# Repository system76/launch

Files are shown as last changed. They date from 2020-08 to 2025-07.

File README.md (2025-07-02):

# System76 Launch Configurable Keyboard

The System76 Launch Configurable Keyboard is designed to provide the ultimate
user controlled keyboard experience, with open source mechanical and electrical
design, open source firmware and associated software, and a large number of
user configuration opportunities. It is registered open source hardware with
[OSHWA UID US001062](https://certification.oshwa.org/us001062.html).

- [Mechanical Design](#mechanical-design)
- [Electrical Design](#electrical-design)
- [Firmware and Software](#firmware-and-software)

## Mechanical Design

Chassis Image

### Open Source Chassis

The Launch chassis is licensed CC-BY-SA-4.0 and can be viewed in the
[chassis](./chassis/) folder using [FreeCAD](https://www.freecad.org).

### Milled Aluminum

The chassis is milled from two solid blocks of aluminum and powder coated to
provide excellent fit and finish. Each pocket, port, and hole is designed and
precisely machined so that swapping switches and plugging in cables is easy and
secure for the user.

### Detachable Lift Bar

The included lift bar can be magnetically secured to add 15 degrees of angle to
your keyboard for ergonomics.

### Innovative Layout

The layout is designed to provide a large number of remapping opportunities.
The default layout can be viewed
[here](http://www.keyboard-layout-editor.com/#/gists/8ec5e9026d616ebad6b2c7e9d943e7c0),
and the extra keys included can be viewed
[here](http://www.keyboard-layout-editor.com/#/gists/a3ad8710b27f78fd938077b2bf6d3ef5).

### Swappable Keycaps

The keycaps are PBT material with a dye sublimation legend and XDA profile to
provide excellent feel and lifespan. Extras are provided for common replacements
and color preference. An included keycap puller can be used to move and replace
the keycaps.

### Swappable Switches

The switches are mounted in sockets that support any RGB switch with an MX
compatible footprint. Examples are the Cherry MX RGB switches and the Kailh
BOX switches. Switches can be removed easily at any time with the included
switch puller.

## Electrical Design

PCB Image

### Open Source PCB

The Launch PCB is licensed GPLv3 and can be viewed in the
[pcb](./pcb/) folder using [KiCad](https://kicad.org/).

### Integrated Dock

Launch connects to a computer using the included USB-C to USB-C cable or USB-C
to USB-A cable. It supports USB 3.2 Gen 2 with speeds up to 10 Gbps with either
cable, provided the computer supports these speeds. It provides 2 USB-C and 2
USB-A connectors that also support USB 3.2 Gen 2, with the 10 Gbps bandwidth
shared between them on demand.

### Independent RGB Lighting

Each switch has an RGB LED that is independently controlled by firmware. This
allows for a number of RGB LED patterns to be selected.

### N-Key Rollover

The keyboard matrix uses diodes on all intersections, providing full independent
scanning of each key position.

## Firmware and Software

### Open Source Firmware

The Launch firmware is based on [QMK](https://github.com/system76/qmk_firmware),
licensed GPLv2, and the latest version is linked in the `firmware` submodule.

### Open Source Software

Projects that integrate with Launch are open source software, such as the
[System76 Keyboard Configurator](https://github.com/pop-os/keyboard-configurator),
licensed GPLv3, and [fwupd](https://github.com/fwupd/fwupd/), licensed LGPLv2.1.

### Easy Remapping

The keyboard can be remapped at runtime using the
[System76 Keyboard Configurator](https://github.com/pop-os/keyboard-configurator).
This utility runs on Linux, Mac OS, and Windows.

### Firmware Updates

Firmware updates are supported through the
[fwupd](https://github.com/fwupd/fwupd/) project, and are distributed using the
related Linux Vendor Firmware Service. Settings are stored on EEPROM and are
maintained through firmware updates.

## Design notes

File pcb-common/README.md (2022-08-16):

# Version Pins PB4-PB7

These are only present on boards with the AT90USB646 microcontroller
(Lite, Launch 2).

Pin PE1 will be grounded if a numeric keypad is present.

| Version | PB4  | PB5  | PB6  | PB7  |
|---|---|---|---|---|
| Lite 1.0 | open | open | open | open |
| Lite ISO 1.0 | open | open | open | open |
| Launch 2.0 | GND  | open | open | open |
| Launch ISO 2.0 | GND  | open | open | GND  |

# Part Substitutions

#### USB7xx6 USB hub

Can use USB7206 or USB7006 any PCB, USB7216 on any PCB >= Launch
1.1. Note that USB7006 is only Gen 1 USB.

 - USB7206: original, do not install R18, R28 if using, Gen 2 (10 Gb/s)
 - USB7216: alternate, install R18, R28, Gen 2 (10 Gb/s), has built Type-C support for 1 port which we are not using to retain ability to use USB7206.
 - USB7006: alternate, do not install R18, R28 if using, Gen 1 (5 Gb/s)

#### PTN5111 Type-C port controller

NXP introduced the PTN5110NHQZ and discontinued all others in the
PTN5110 line. It defaults to a toggling dual role port, will need to
be configured by software for the downstream facing ports. The
upstream facing port should select the correct mode. No hardware
changes are required.

 - PTN5110THQ: original for downstream ports (U12, U13), defaults to sourcing power
 - PTN5110DHQ: original for upstream port (U11), defaults to sinking power
 - PTN5110NHQZ: replacement, defaults to dual role port, same part used all 3 locations

#### Buck converters

Changes were all due to availability problems. Each part only works
with the listed PCB revisions.

 - TI TLV62585PDRL: Launch 1.0, 1.1
 - Diodes Inc. AP3441LSHE-7B: Launch 1.2, 1.4
 - Diodes Inc. AP61302: Launch 1.3
 - Aerosemi M3406-ADJ: Launch Lite 1.0 (includes ISO)
 - Aerosemi MT3410LB: Launch 2.0 (includes ISO)

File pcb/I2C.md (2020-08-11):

I2C addresses in this document include the R/W bit.

# USB Hub @ 0x5A

As I2C pullups are present on this board, the hub will wait for configuration before becoming active. The upstream superspeed mux should be set first.

# Type C Port Controllers (TCPC)
 - Register information is in PTN5110_AN2137.pdf rather than the data sheet.
 - The FRS pin is used as a GPIO to control the superspeed mux. See EXT_GPIO_CONFIG/CONTROL registers.
 - The interrupt pin is not wired due to lack of pins on the AVR. The TCPCs will need to be periodically polled. 
 - All support full USB PD communication, but this does not have to be used
 - Can source VCONN for active cables, electronic markers

## Upstream @ 0xA2
 - The CC_STATUS reigster can be read to determine connector orientation and available power.
 - A PD contract may allow more power than indicated in CC_STATUS, for example, a device that can source 2 A would report 1.5 A via CC_STATUS.
 - PTN5110DHQ which defaults to acting as a power sink.
 - Defaults should be OK except for GPIO setup on FRS.
## Downstream C Left @ 0xA4, Right @ 0xA0
 - PTN5110THQ which defaults to acting as a power source
 - The AVR will need to poll for cable connects and disconnects. tVbusOFF in the USB C spec is 650 ms which sets the maximum polling interval.
 - The SRC pin is used on the downstream ports to enable sourcing power. It may be required to switch the SRC pin to a GPIO so that sourcing power is only enabled after the superspeed mux is set properly.
 - It's probably best to only offer default power.

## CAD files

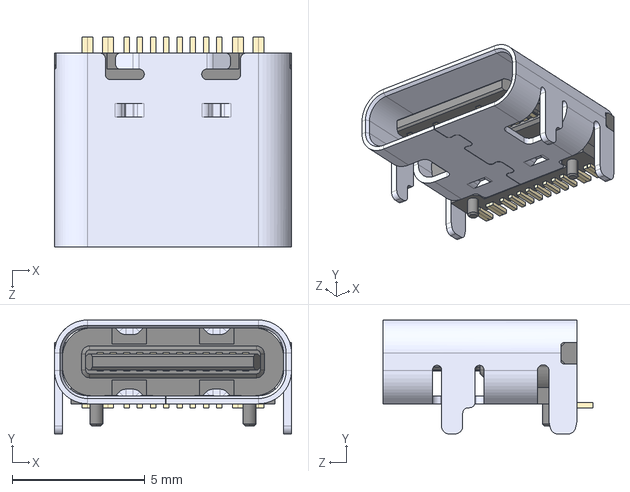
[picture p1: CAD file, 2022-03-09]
pcb/models/TYPE-C-31-M-12--3DModel-STEP-56544.STEP
8.94 x 4.30 x 7.90 mm

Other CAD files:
chassis/shared-components/CAD/AS_TEST_STABIL_ASM v2.step
chassis/launch-heavy/CAD/Key Caps.step
chassis/launch/CAD/KEYALU-002001.step
chassis/shared-components/CAD/PN-000173.step
packaging/Launch_Packaging_reference.step
pcb/models/GT-TC025D-H0065.step
chassis/launch-heavy/CAD/PN-000337 v19.step
chassis/launch-lite/CAD/PN-000166 v14.step
pcb/models/SOD128.step
chassis/launch-heavy/CAD/PN-000338 v10.step
chassis/launch-lite/CAD/PN-000164 v32.step
chassis/launch/CAD/Launch V1.step
pcb/models/AFC07-S20FCC-00.step
chassis/launch-heavy/CAD/PN-000336 v7.step
chassis/launch/CAD/KEYALU-001001.step
chassis/shared-components/CAD/PN-000163 v6.step
chassis/launch-heavy/CAD/Heavy Production V1.step
chassis/launch-heavy/CAD/PCB V1 - Physical Place Holder.step
chassis/launch-heavy/CAD/PN-000336 v7.f3d
chassis/launch-heavy/CAD/PN-000337 v19.f3d
chassis/launch-heavy/CAD/PN-000338 v10.f3d
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

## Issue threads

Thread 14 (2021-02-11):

North-facing switch socket interference

powwu, 2021-02-11:
Hello there!

This is just to let you know that, whether intentional or not, your board uses north facing switch sockets. This is not an issue with the included XDA profile caps, but when you switch in aftermarket caps, such as Cherry profile keycaps, [interference is possible](https://youtu.be/pFySgr0xmPw). This causes muffled sound and a bottom-out that feels mushy and uneven. Usually, north facing switch sockets are there to provide better RGB lighting when a key is "backlit" (transparent legending), but this is not the case here. This is a decently significant issue, because Cherry profile keycaps are the most popular among aftermarket keycaps. If you do a revision in the future, I recommend making your switch sockets south-facing.

jackpot51, 2021-02-11:
We have not seen (heard?) any such issue, and have used other keycaps in testing. I think the way the switch is plate mounted is pretty important

lennihein, 2021-02-12:
The issue exists, and is widely known by people that ever had any interest in keyboards. A design choice that doesn't make me very confident in the overall process of designing this board.

VinnyCordeiro, 2021-02-12:
> A design choice that doesn't make me very confident in the overall process of designing this board.

Agreed. I was excited about a new player on the market, specially one that promotes open source solutions like System76, but after taking a look at the design, being a keyboard PCB designer myself, the excitement cooled down significantly. That's unfortunate.

leviport, 2021-02-12:
To clarify: this is _only_ an issue with Cherry profile's row 4 keycaps. Pretty much all of the other keycap profiles out there (including the XDA caps this board was designed with and will ship with) do not interfere with north-facing switches.

> but after taking a look at the design, being a keyboard PCB designer myself, the excitement cooled down significantly. That's unfortunate.

Thanks for the feedback, but it's not very constructive. Is anything other than the switch orientation a big issue? We can only improve if we know where we went wrong.

WatchMkr, 2021-02-12:
Thank you for your input. It's appreciated. I am not experiencing interferences issue with cherry profiles. We tested DSA, XDA, Cherry, and VSA.

https://user-images.githubusercontent.com/3430283/107816382-e8b60480-6d31-11eb-93a3-b1d715d7a25a.MOV

lennihein, 2021-02-12:
I am quite fond of System76 overall, so I really want this to succeed. Heavily recommend to get a lot of input from both the Linux (user) and Keyboard Enthusiast (experts) communities to create a product that meets the bar.

WatchMkr, 2021-02-12:
Thanks again. The orientation is intentional. We did not want LEDs shining out from below the lower portion of the keycap.

Closed 2021-02-12.

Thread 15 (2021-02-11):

Where's the link to buy this one ?

alexserver, 2021-02-11:
In the readme there's no link to a store or form to buy this one.
Also, it doesn't say whether this keyboard is just in the design phase, or already in production.
Can you put the enough information in your readme to clarify this questions ?
- is it on sale already ?
- is this only a design ?
- where are the schemas to build one ?
- do I have to build the PCB using PCB printing services ?
- do you have plans to sell this one ?

leviport, 2021-02-11:
The readme is not a blog post or official announcement, so that information wouldn't be relevant here. This is just where all the source code lives. They are not ready for sale quite yet, but we will make announcements in all of the usual places when they are selling. All of the design files are in this repo, so you can try making one yourself if you want to.

Closed 2021-02-11.

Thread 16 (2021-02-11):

Cannot Open step Files in FreeCAD

monty11ez, 2021-02-11:
I'm using the current version in the Arch repos 0.18.5 and I get an error trying to open the file.

bflanagin, 2021-02-11:
Hey @monty11ez what step file are you trying to open? I was able to open up Launch V1.step using FreeCAD 0.18.5. I'll try the others for good measure, but knowing which one you tried would make things faster.

jacobgkau, 2021-02-11:
Are you seeing this error?

```
Traceback (most recent call last):
  File "<string>", line 1, in <module>
<class 'OSError'>: cannot read STEP file
```

If so, please initialize Git LFS on your system: https://git-lfs.github.com/

Then re-clone the repository and try opening the file again. (Until Git LFS is initialized, you would only be getting pointer text files when clonning the repo.) I can confirm FreeCAD opens the STEP files:

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

jackpot51, 2021-02-11:
I think we need to add instructions to the README, since many files are stored using GIT LFS and also we use submodules.

This is the correct way to clone the project:
```
git lfs install
git clone --recursive https://github.com/system76/launch.git
```

ultrasiq, 2021-02-13:
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

I did this and still can't open the .step files.

frankk74, 2021-02-22:
Step files are not fcstd files. They are an output file of CAD systems that cannot be used to edit (or very slightly). You can "import" step/stp or stl files and look at the design but it is not the full editable design. If possible can you post the fcstd files? I just wanted to look at the design elements. However, not choosing to post them to stop some other company from cloning your design is completely understandable. Thank you for posting the info that you have. Mind I couldn't find the info about the price/availability.

jackpot51, 2021-02-22:
@frankk74 the design is made in AutoCAD 360. There are STEP files of the assembly in various states. Individual parts as well as the full assembly. This is enough to import into other software like FreeCAD for editing.

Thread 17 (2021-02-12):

Remove reset to firmware command

jackpot51, 2021-02-12:
This was implemented in https://github.com/system76/qmk_firmware/commit/a1ab70c3a28a773aa116d2e37c3e597ca4c53c5b to make the flashing process easier.

However, this increases the risk that malicious keyboard firmware is installed without the user's consent. Therefore, remove the reset command and require the reset keycode (Fn+Esc) to be pressed, or the boot magic code (Esc while plugging in the keyboard) to reboot to the bootloader.

The risk is even higher when using an OS that does not require administrator privileges to access USB devices, such as Windows. And since we, by design so the user can customize things, do not have signed firmware - this means any application could potentially reflash the keyboard firmware.

By requiring a physical keypress to reboot the bootloader, at least the user will have to intentionally set the keyboard into this mode before firmware can be written.

jackpot51, 2021-02-25:
The firmware has been adjusted to require a manual unlock before it can be reset to bootloader and flashed.

Closed 2021-02-25.

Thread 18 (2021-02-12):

Feature request:  bluetooth version

ByteEnable, 2021-02-12:
Feature request:  bluetooth version.

leviport, 2021-02-12:
This request lacks information. If you can elaborate, I can reopen this issue.

ByteEnable, 2021-02-12:
The addition of a Bluetooth controller to the PCB for wireless keyboarding.

leviport, 2021-02-12:
Ah, a bluetooth version of the keyboard. Sorry, I'm not sure why I had trouble figuring out what you meant.

Thanks for the suggestion. I don't think the dock functionality is going to work well over bluetooth, and we're past the point of being able to make such major PCB revisions anyway. Perhaps bluetooth can come in future iterations though.

ruffsl, 2021-06-30:
> Perhaps bluetooth can come in future iterations though.

If one was to modify the current PCB design to include a bluetooth chipset for this functionality, would anyone have some recommendation on chipsets or radio ICs? A vendor with a friendly open source ecosystem for firmware and bluetooth profiles?

Closed 2021-02-12.

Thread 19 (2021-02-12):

Feature/Design request: Possibility to convert from ANSI to ISO standard

avila, 2021-02-12:
### Description:

It is great to hear you at system76 are producing a keyboard!  From the pictures I've seem so far it looks like the keyboard will follow the ANSI (American National Standards Institute) standard. It would be great if it would be possible to "switch" to the ISO standard. It mostly affects the `Enter` and `Shift` keys. See images below.

If this is physically impossible at this stage, please consider adding this feature in the next revisions.

### ISO keyboard standard:

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

### ANSI layout:

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

### System76 layout (looks like follows ANSI standard):

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

ogarcia, 2021-02-13:
And a full version with numpad

fuzebox1, 2021-03-29:
Id like to second this. I would really appreciate a ISO standards CAD and board layout file so i can print at home and have a board made locally! Although if you make one available for sale id definitely buy it when I finally buy a thelio :)

izzycampbell, 2021-03-29:
How much?

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

cooperspencer, 2025-07-12:
That would be great. I would immediately buy one

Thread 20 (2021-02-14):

Power (USB PD)

thibaultmol, 2021-02-14:
How many watts can the keyboard handle to charge a phone for example? Does it have USB PD?

jackpot51, 2021-02-15:
It does not have USB PD. The wattage delivered depends on the connection to the computer. If it is connected over USB-C, then a phone connected into a downstream USB-C port will be able to use around 15 watts

jackpot51, 2021-02-15:
A big reason it doesn't have USB-PD, is that computer motherboards do not support being a USB-PD source, and laptops are usually a sink but almost never a source. So it would require an additional AC adapter for full functionality

thibaultmol, 2021-02-15:
> A big reason it doesn't have USB-PD, is that computer motherboards do not support being a USB-PD source, and laptops are usually a sink but almost never a source. So it would require an additional AC adapter for full functionality

oh, interesting. Hadn't thought of that actually 👍

iMonZ, 2021-02-17:
> A big reason it doesn't have USB-PD, is that computer motherboards do not support being a USB-PD source, and laptops are usually a sink but almost never a source. So it would require an additional AC adapter for full functionality

Thats sad
but the idea of PD is still really great!

Closed 2021-02-15.

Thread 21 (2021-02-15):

TrackPoint (like Lenovo has) would be great.

guettli, 2021-02-15:
I am addicted to a TrackPoint, since it helps me to switch between typing and moving the mouse easily.

It would be great if you could provide something like this.

timvisee, 2021-02-15:
I agree! Though I'm afraid it won't fit between the mechanical switches without spacing the keys.

jackpot51, 2021-02-15:
We thought about it, but it was not easy to fit it into the reconfigurable design because it requires the GHB keycaps to have their corners clipped where the trackpoint would go. Additionally, finding trackpoint hardware is not easy

gzeronet, 2021-02-18:
Couldn't agree any more.
https://github.com/gzeronet/teensy-trackpoint-tmk-keyboard.git
https://github.com/gzeronet/tp60.git
It works for me, hope that can help. :)

Closed 2021-02-15.

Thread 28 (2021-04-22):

Add delay to escape key to avoid acidental reset

bflanagin, 2021-04-22:
When working on my computer yesterday my headphones tipped over and pressed the escape key on the launch right as I plugged in the device. This was a million in one shot, but it left my keyboard in a state that seemed broken until I reset the cable a second time.

To test:
Unplug the USB-C cable from the back of the keyboard. Just as you plug the cable back in slightly tap the escape key.

Solution:
If possible adding a small delay between power and checking for the escape key press might keep the device from being reset unintentionally.

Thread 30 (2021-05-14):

consider releasing the CAD source files

EllaBarker, 2021-05-14:
To keep the opensource/open hardware mindset I would appreciate it if the native CAD files get released beside the STEP ones.

jgrano, 2021-05-17:
Hi - The Step file is a much cleaner way to view the design/code if that's your thing. Our in house file format is F3D as we use Fusion 360 for design & manufacturing. Using Step is as close to universal as we can get so any can platform can import the design and you can modify as needed. We can easily import that changes as needed based on a Step file.

EllaBarker, 2021-05-17:
Releasing the STEP is the right decision as any program can import it but offering the native format, in addition, would be beneficial as modifying the native format is a better experience. That's in line with the recommendations from the OSHW: [https://www.oshwa.org/sharing-best-practices/](https://www.oshwa.org/sharing-best-practices/)
Just a simple, generic example: extend the case by 5 mm. With a native format, the only change would be updating the parameter. With step it is much more complicated and the easiest solution might be cut body, move, and inserting the new part in between.

There is software that claims they can convert a step, obj, igs, etc. back to native formats but in most cases, it fails miserably.

jgrano, 2021-06-25:
Haven't forgotten about this - I am unable to export the full assembly in a *.f3d format due to the distributed nature of the structure. A full step file export is the only option currently. I am pushing up the chassis designs in their native format.

Closed 2021-06-25.

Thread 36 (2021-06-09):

Feature request / bug report: Change USB-A type socket alignment

mvdkleijn, 2021-06-09:
## What?
From my perspective, the USB-A sockets are upside down.

## Reasoning
While I was unable to (quickly) find a relevant specification entry with regards to orientation, most reference images for the socket layout have the pin connectors located at the **top** of the socket. The same goes for the practical application on many, if not most or even all laptops. The pin connectors are at the top.

In the current keyboard design, the connector pins are at the bottom. This would force the user to turn around the USB-A type plug in order to insert it into the socket.

Though the orientation would in many cases probably not matter, there are important benefits to have the socket the right way up.

## Example
An important example is to allow for the insertion of a USB-A type security key such as promoted by the likes of Github and Google. Specifically the design of something like the Yubikey.

This would allow a user to insert the security key into the keyboard instead of the lap/desktop. This kind of key works fine on laptops because of the orientation of the USB-A type socket. However, the Launch keyboard's orientation would block a user from touching the confirmation button on the security key.

I hope you will be able to turn around the sockets... even better would be if a socket could be located on the right or left of the keyboard for easier access to the security key when you need to hit the confirmation button. 😄

jackpot51, 2021-06-17:
It has been impossible to find USB-A connectors that support 3.2 Gen 2 speeds that can be mounted on the same side but have the orientation reversed. To do this would mean pretty considerably increasing the size of the chassis

mvdkleijn, 2021-07-01:
> It has been impossible to find USB-A connectors that support 3.2 Gen 2 speeds that can be mounted on the same side but have the orientation reversed. To do this would mean pretty considerably increasing the size of the chassis

That's too bad... 😞 😢  Otherwise this would've been perfect. I guess I'll close this issue then.

Closed 2021-07-01.

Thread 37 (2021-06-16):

Shipping to China

eret9616, 2021-06-16:
I'm living in China mainland, In the Checkout process, there is no China , will there be adding this country

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

izzycampbell, 2021-06-16:
United States and what are you shipping anyways?

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

Closed 2021-06-17.

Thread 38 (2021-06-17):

Please see discussion on keebtalk

dkrikun, 2021-06-17:
Just have a look there, ok?

https://www.keebtalk.com/t/system76-open-source-hotswap-mechanical-keyboard/12946

mmstick, 2021-06-17:
Not worth wasting anyone's time.

jackpot51, 2021-06-17:
@dkrikun I really don't get how so many people can miss the fucking point so much

dkrikun, 2021-06-17:
Maybe you could elaborate?

jackpot51, 2021-06-17:
Sure, though I doubt it will matter. Most of the complaints I see center around the layout and the price.

**Layout**

The layout is specifically designed to minimize changes from the standard layout while introducing several impactful changes that show up on literally no other keyboards. Some mistake this for a lack of research when the exact opposite is true. We experimented heavily with common layouts, including ortholinear, split ortholinear, and staggered. We experimented with the "standard" key sizes, where the left side would line up perfectly, but would also use 1.25, 1.75, and 2.25 size keys. After a ton of prototypes, we arrived at this layout. Our first task was to reduce the number of key sizes, to maximize where keys could be swapped. This led to the left side and right side being uneven, but in a way I think looks good once you actually use the keyboard. We also split the spacebar, to allow both side to be mapped independently, and allow the caps to be swapped with anything else that has a 2U cap. We include tons of extras to ensure most keys can be put most anywhere. Keep in mind, that while enthusiasts don't care if caps are blank, most users do. This is a keyboard we want any of our customers to be able to use.

**Electrical Design**

Some absolute idiot suggested we have 5 USB ports as though it was a dumb idea. We do, but one is for connecting to the PC. So we have two USB-A and two USB-C ports on each side of that central connector to the PC, it is balanced and even and sensible. To have a 4-port 10Gbps USB hub inside a keyboard, certain things have to be done with the electrical layout. Trying to make it "pretty" is a mistake. Our layout is designed to maximize the USB lane integrity, critical for any high speed design. The switches themselves operate at extremely low frequency compared. We are talking 10 GHz compared to 1 KHz, several orders of magnitude lower. So, the switch and LED lines are moved around to make substantial room for ground planes and the important USB lines. It was not auto-routed AT ALL, this was done by hand with a careful consideration for high speed design requirements.

**Price**

Sure, you can have a 75% for less. With a metal chassis, good caps, and good switches you are approaching the Launch price. Throw in an integrated 4-port 10Gbps USB hub, and you won't find anything else available. Make it not integrated, and you still end up around the price we have for this keyboard. Our costs and profit margins are well researched and match those of other keyboards. If anything, we are in a position to outperform them on price in the future, as we have seen incredible demand for this product from our customers.

jackpot51, 2021-06-17:
Put that reply up on keebtalk because I'm so damn tired of the hate of this product building out of control:

https://www.keebtalk.com/t/system76-open-source-hotswap-mechanical-keyboard/12946/46?u=jackpot51

Closed 2021-06-17.

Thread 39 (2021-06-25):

request: rendered pdf schematic

hanetzer, 2021-06-25:
I'm running kicad nightly (I think the 6.0 release should come soon) and as such have to remap a fair
amount of symbols in the schematic. It would be very helpful to this endeavor if a rendered pdf of how
it 'should' look was included in the repository in case something is not clear from the old-style symbol
names.

leviport, 2021-06-25:
Are the PDFs in the `Drawings` directory what you had in mind? https://github.com/system76/launch/tree/master/chassis/Drawings

Sorry if I'm missing your meaning. I'm not very well-versed in CAD related matters :sweat_smile:

jackpot51, 2021-06-25:
This is schematics for electrical design. Currently we use KiCad 5.1.9. I can render them a bit later.

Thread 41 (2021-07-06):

Programming for Each OP for VF-5

CCooper20, 2021-07-06:

CCooper20, 2021-07-06:
Simulator for VF-5 with correct parameter
Program with 5 pallets for each:

- [ ] OP1-UH
- [ ] OP2-UH
- [ ] OP3-UH
- [ ] OP1-LH (vacuum system)
- [ ] OP2-LH (vacuum system)
- [ ] OP1-AB
- [ ] OP2-AB

- [ ] Sub program for chip fan

*pattern for programs / sub programs
*assigned G## for each pallet and color coordinated

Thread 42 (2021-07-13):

Work flow for Launch within Production

CCooper20, 2021-07-13:
Detailed document laying out each step for making LH, UH, AB and assembly.
Attached QC layout of checking imported parts.

CCooper20, 2021-07-13:
Work flow for each part, assembly and imported parts:

- [ ] LH
- [ ] UH
- [ ] AB

- [ ] Assembly

- [ ] Testing

- [ ] Imported parts

CCooper20, 2021-07-13:
Here is the current doc: [https://docs.google.com/presentation/d/1gIdjVxumpAt9Q0GdWsTyjt4Vi-lHfbOouB-Df1y45Go/edit?usp=sharing] (url)

CCooper20, 2021-08-02:
Where is the link again for this process and where are we at with documenting the assembly and also checking imported parts? @jgrano

jgrano, 2021-08-02:
@CCooper20 Import doc - https://docs.google.com/document/d/1v5RxfDeCSvyY8Mp5XGhm-rX4il3qUbCLlkyPOkBjI2c/edit?usp=sharing

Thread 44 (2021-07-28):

Implement OP1 / OP2 Vacuum process for LH

CCooper20, 2021-07-28:
New CNC programs / WI / QC checks

CCooper20, 2021-07-28:
- [ ] Design / Setup CNC toolpaths for vac pallets LH
- [ ] Setup Vacuum pallets for OP1 / OP2 LH
- [ ] Test

*made total of 5 complete pieces. Need to adjust T1 just for OP1-LH - 7/21/21

- [ ] Install vacuum pressure sensor on Haas
- [ ] WI for Vacuum pallets setup / main. and break down

- [ ] WI for OP1/OP2 LH
- [ ] Train Production to hand off - rev Work flow and CNC WI to match changes after we went through version 1 of LH pallets

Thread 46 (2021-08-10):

Update Drawings

jgrano, 2021-08-10:
Update Full Drawings based on new production methods

CCooper20, 2021-08-12:
Update Drawings for Launch:

Make sure all drawings are in one location and same template.

- [ ] KEYALU-003002 (last version of angle bar)
- [ ] KEYALU-003001 (obsolete drawing)
- [ ] KEYALU-001001
- [ ] KEYALU-002001
- [ ] Launch assembly drawing
- [ ] Launch steel plate / fix to steel disk

42Surtr, 2021-08-17:
Could any one can point out which of the file is the PCB file, which file can be checked and modified to build a pcb file?

leviport, 2021-08-17:
@42Surtr it's in the `pcb` directory: https://github.com/system76/launch/tree/master/pcb

42Surtr, 2021-08-19:
Thanks for your help.  There is anohter question for me is that is this PCB designed as a single layer PCB?  The PCB file is a little difficult to understand for me.

jackpot51, 2021-08-19:
@42Surtr it is a four layer PCB

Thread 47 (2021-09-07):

Failing to flash the Launch keyboard's firmware.

uncivilgentleman, 2021-09-07:
Following the documentation I'll link to on the bottom.  I modified the keymap.c file the way I wanted it.  The problem is the instructions to send the new .hex file to the keyboard aren't working.  It compiles just fine but I keep getting the ERROR: Bootloader not found. Trying again in 5s. even after unplugging the keyboard and plugging it back in while holding the ESC key.   The keyboard lights don't turn on but the error persists and nothing gets uploaded to the keyboard.

https://github.com/system76/qmk_firmware/blob/master/keyboards/system76/launch_1/README.md

_I realize this probably isn't the best place to post this problem but I can't find a better place.  All the official social platforms to engage with the company and its community seem to be proprietary social media platforms like Facebook, Twitter, and Telegram. I don't want to be a part of those places._

leviport, 2021-09-07:
Are you holding Esc while plugging in your Launch? It can be released a couple seconds after Launch is plugged in. Are you doing that while it's cycling that Bootloader not found message?

uncivilgentleman, 2021-09-07:
yes I'm holding ESC while plugging in the keyboard.  I've also tried different USB ports (Type A and C) on the computer.

leviport, 2021-09-07:
Hmm, what happens if you hold Fn+Esc instead? If that works, then I'll need to update those instructions.

uncivilgentleman, 2021-09-07:
That didn't work either.

uncivilgentleman, 2021-09-07:
I'm on Fedora 34 and not Pop-OS if that matters.   I don't know why it would but I figure I should mention it.

leviport, 2021-09-07:
QMK isn't at all specific to Pop, so that should still work. What version of `avrdude` do you have installed?

uncivilgentleman, 2021-09-07:
avrdude 6.3.  Specifically avrdude-6.3-20.fc34.src.rpm

leviport, 2021-09-07:
I'm also on 6.3. I'm wondering if a udev rule needs to be set or something. I'll spin up F34 on a lab machine and see if I can figure out how to QMK flash my Launch from it.

leviport, 2021-09-07:
Alright, I was able to get it dfu-programmer to recognize my Launch if I ran the make command with `sudo`. It also first asked me to run `util/qmk_install.sh` again, so I also ran that with `sudo`. Can you give that a try?

uncivilgentleman, 2021-09-07:
Yup that works!  I thought about doing that several times, should have.

leviport, 2021-09-07:
Glad to hear it! Not sure why Fedora requires `sudo` for that when Pop doesn't, but I can probably make a note of that in the instructions.

Oh and to address your note about social media platforms, there's also the Pop!\_OS chat where we even have a Launch Keyboard channel. It's a Mattermost instance that we host ourselves, so you can chat with us there without making accounts on social media platforms. You can find it at https://chat.pop-os.org if you're interested.

uncivilgentleman, 2021-09-07:
Awesome!  Thank you for the help :)

Closed 2021-09-07.

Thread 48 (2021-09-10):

Layer LEDs stay on after pressing Fn key

gondolyr, 2021-09-10:
**Software**: System76 Keyboard Configurator 1.0.0
**Operating System**: Windows 10 (10.0.19041 Build 19041)
**Firmware Version**: Launch 1.3?

My configuration is set up to turn on the LEDs for the bound keys on layers 2+. Every 13-20 presses (on average) of using the Fn key to Play/Pause the current media file, the LEDs stay on after I have let go of the Fn key. If I press the Fn key again, the LEDs turn off.

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

My current configuration is below:
```json
{
  "model": "system76/launch_1",
  "version": 1,
  "map": {
    "K04": [
      "F4",
      "ROLL_OVER",
      "ROLL_OVER",
      "ROLL_OVER"
    ],
    "K4C": [
      "UP",
      "PGUP",
      "ROLL_OVER",
      "ROLL_OVER"
    ],
    "K42": [
      "X",
      "ROLL_OVER",
      "ROLL_OVER",
      "ROLL_OVER"
    ],
    "K44": [
      "V",
      "ROLL_OVER",
      "ROLL_OVER",
      "ROLL_OVER"
    ],
    "K0C": [
      "F12",
      "ROLL_OVER",
      "ROLL_OVER",
      "ROLL_OVER"
    ],
    "K27": [
      "U",
      "PGDN",
      "ROLL_OVER",
      "ROLL_OVER"
    ],
    "K03": [
      "F3",
      "ROLL_OVER",
      "ROLL_OVER",
      "ROLL_OVER"
    ],
    "K50": [
      "LEFT_CTRL",
      "ROLL_OVER",
      "ROLL_OVER",
      "ROLL_OVER"
    ],
    "K5A": [
      "DOWN",
      "PGDN",
      "ROLL_OVER",
      "ROLL_OVER"
    ],
    "K14": [
      "4",
      "ROLL_OVER",
      "ROLL_OVER",
      "ROLL_OVER"
    ],
    "K57": [
      "RIGHT_ALT",
      "ROLL_OVER",
      "ROLL_OVER",
      "ROLL_OVER"
    ],
    "K37": [
      "J",
      "DOWN",
      "ROLL_OVER",
      "ROLL_OVER"
    ],
    "K46": [
      "N",
      "ROLL_OVER",
      "ROLL_OVER",
      "ROLL_OVER"
    ],
    "K3B": [
      "QUOTE",
      "ROLL_OVER",
      "ROLL_OVER",
      "ROLL_OVER"
    ],
    "K06": [
      "F6",
      "ROLL_OVER",
      "ROLL_OVER",
      "ROLL_OVER"
    ],
    "K41": [
      "Z",
      "ROLL_OVER",
      "ROLL_OVER",
      "ROLL_OVER"
    ],
    "K21": [
      "Q",
      "ROLL_OVER",
      "ROLL_OVER",
      "ROLL_OVER"
    ],
    "K0A": [
      "F10",
      "ROLL_OVER",
      "ROLL_OVER",
      "ROLL_OVER"
    ],
    "K26": [
      "Y",
      "HOME",
      "ROLL_OVER",
      "ROLL_OVER"
    ],
    "K40": [
      "LEFT_SHIFT",
      "ROLL_OVER",
      "ROLL_OVER",
      "ROLL_OVER"
    ],
    "K52": [
      "FN",
      "ROLL_OVER",
      "ROLL_OVER",
      "ROLL_OVER"
    ],
    "K1D": [
      "BKSP",
      "ROLL_OVER",
      "ROLL_OVER",
      "ROLL_OVER"
    ],
    "K31": [
      "A",
      "ROLL_OVER",
      "ROLL_OVER",
      "ROLL_OVER"
    ],
    "K0B": [
      "F11",
      "ROLL_OVER",
      "ROLL_OVER",
      "ROLL_OVER"
    ],
    "K36": [
      "H",
      "LEFT",
      "ROLL_OVER",
      "ROLL_OVER"
    ],
    "K33": [
      "D",
      "ROLL_OVER",
      "ROLL_OVER",
      "ROLL_OVER"
    ],
    "K43": [
      "C",
      "ROLL_OVER",
      "ROLL_OVER",
      "ROLL_OVER"
    ],
    "K07": [
      "F7",
      "ROLL_OVER",
      "ROLL_OVER",
      "ROLL_OVER"
    ],
    "K2A": [
      "P",
      "ROLL_OVER",
      "ROLL_OVER",
      "ROLL_OVER"
    ],
    "K4B": [
      "RIGHT_SHIFT",
      "ROLL_OVER",
      "ROLL_OVER",
      "ROLL_OVER"
    ],
    "K54": [
      "SPACE",
      "ROLL_OVER",
      "ROLL_OVER",
      "ROLL_OVER"
    ],
    "K5B": [
      "RIGHT",
      "END",
      "ROLL_OVER",
      "ROLL_OVER"
    ],
    "K00": [
      "ESC",
      "RESET",
      "ROLL_OVER",
      "ROLL_OVER"
    ],
    "K0E": [
      "HOME",
      "PLAY_PAUSE",
      "ROLL_OVER",
      "ROLL_OVER"
    ],
    "K11": [
      "1",
      "ROLL_OVER",
      "ROLL_OVER",
      "ROLL_OVER"
    ],
    "K18": [
      "8",
      "ROLL_OVER",
      "ROLL_OVER",
      "ROLL_OVER"
    ],
    "K2C": [
      "BRACE_CLOSE",
      "ROLL_OVER",
      "ROLL_OVER",
      "ROLL_OVER"
    ],
    "K1B": [
      "MINUS",
      "KBD_DOWN",
      "ROLL_OVER",
      "ROLL_OVER"
    ],
    "K1C": [
      "EQUALS",
      "KBD_UP",
      "ROLL_OVER",
      "ROLL_OVER"
    ],
    "K55": [
      "SPACE",
      "ROLL_OVER",
      "ROLL_OVER",
      "ROLL_OVER"
    ],
    "K2E": [
      "PGDN",
      "VOLUME_DOWN",
      "ROLL_OVER",
      "ROLL_OVER"
    ],
    "K29": [
      "O",
      "END",
      "ROLL_OVER",
      "ROLL_OVER"
    ],
    "K39": [
      "L",
      "RIGHT",
      "ROLL_OVER",
      "ROLL_OVER"
    ],
    "K4A": [
      "SLASH",
      "ROLL_OVER",
      "ROLL_OVER",
      "ROLL_OVER"
    ],
    "K53": [
      "LEFT_SUPER",
      "ROLL_OVER",
      "ROLL_OVER",
      "ROLL_OVER"
    ],
    "K16": [
      "6",
      "ROLL_OVER",
      "ROLL_OVER",
      "ROLL_OVER"
    ],
    "K19": [
      "9",
      "ROLL_OVER",
      "ROLL_OVER",
      "ROLL_OVER"
    ],
    "K10": [
      "TICK",
      "ROLL_OVER",
      "ROLL_OVER",
      "ROLL_OVER"
    ],
    "K28": [
      "I",
      "PGUP",
      "ROLL_OVER",
      "ROLL_OVER"
    ],
    "K56": [
      "RIGHT_CTRL",
      "ROLL_OVER",
      "ROLL_OVER",
      "ROLL_OVER"
    ],
    "K34": [
      "F",
      "ROLL_OVER",
      "ROLL_OVER",
      "ROLL_OVER"
    ],
    "K35": [
      "G",
      "ROLL_OVER",
      "ROLL_OVER",
      "ROLL_OVER"
    ],
    "K15": [
      "5",
      "ROLL_OVER",
      "ROLL_OVER",
      "ROLL_OVER"
    ],
    "K32": [
      "S",
      "ROLL_OVER",
      "ROLL_OVER",
      "ROLL_OVER"
    ],
    "K1A": [
      "0",
      "KBD_TOGGLE",
      "ROLL_OVER",
      "ROLL_OVER"
    ],
    "K51": [
      "LEFT_ALT",
      "ROLL_OVER",
      "ROLL_OVER",
      "ROLL_OVER"
    ],
    "K2D": [
      "BACKSLASH",
      "ROLL_OVER",
      "ROLL_OVER",
      "ROLL_OVER"
    ],
    "K48": [
      "COMMA",
      "MEDIA_PREV",
      "ROLL_OVER",
      "ROLL_OVER"
    ],
    "K45": [
      "B",
      "ROLL_OVER",
      "ROLL_OVER",
      "ROLL_OVER"
    ],
    "K08": [
      "F8",
      "ROLL_OVER",
      "ROLL_OVER",
      "ROLL_OVER"
    ],
    "K0D": [
      "DEL",
      "ROLL_OVER",
      "ROLL_OVER",
      "ROLL_OVER"
    ],
    "K12": [
      "2",
      "ROLL_OVER",
      "ROLL_OVER",
      "ROLL_OVER"
    ],
    "K05": [
      "F5",
      "ROLL_OVER",
      "ROLL_OVER",
      "ROLL_OVER"
    ],
    "K02": [
      "F2",
      "ROLL_OVER",
      "ROLL_OVER",
      "ROLL_OVER"
    ],
    "K17": [
      "7",
      "ROLL_OVER",
      "ROLL_OVER",
      "ROLL_OVER"
    ],
    "K23": [
      "E",
      "ROLL_OVER",
      "ROLL_OVER",
      "ROLL_OVER"
    ],
    "K58": [
      "FN",
      "ROLL_OVER",
      "ROLL_OVER",
      "ROLL_OVER"
    ],
    "K59": [
      "LEFT",
      "HOME",
      "ROLL_OVER",
      "ROLL_OVER"
    ],
    "K38": [
      "K",
      "UP",
      "ROLL_OVER",
      "ROLL_OVER"
    ],
    "K13": [
      "3",
      "ROLL_OVER",
      "ROLL_OVER",
      "ROLL_OVER"
    ],
    "K30": [
      "CAPS",
      "ROLL_OVER",
      "ROLL_OVER",
      "ROLL_OVER"
    ],
    "K1E": [
      "PGUP",
      "VOLUME_UP",
      "ROLL_OVER",
      "ROLL_OVER"
    ],
    "K2B": [
      "BRACE_OPEN",
      "ROLL_OVER",
      "ROLL_OVER",
      "ROLL_OVER"
    ],
    "K3C": [
      "ENTER",
      "ROLL_OVER",
      "ROLL_OVER",
      "ROLL_OVER"
    ],
    "K49": [
      "PERIOD",
      "MEDIA_NEXT",
      "ROLL_OVER",
      "ROLL_OVER"
    ],
    "K01": [
      "F1",
      "ROLL_OVER",
      "ROLL_OVER",
      "ROLL_OVER"
    ],
    "K47": [
      "M",
      "ROLL_OVER",
      "ROLL_OVER",
      "ROLL_OVER"
    ],
    "K3A": [
      "SEMICOLON",
      "ROLL_OVER",
      "ROLL_OVER",
      "ROLL_OVER"
    ],
    "K20": [
      "TAB",
      "PRINT_SCREEN",
      "ROLL_OVER",
      "ROLL_OVER"
    ],
    "K3D": [
      "END",
      "MUTE",
      "ROLL_OVER",
      "ROLL_OVER"
    ],
    "K24": [
      "R",
      "ROLL_OVER",
      "ROLL_OVER",
      "ROLL_OVER"
    ],
    "K25": [
      "T",
      "ROLL_OVER",
      "ROLL_OVER",
      "ROLL_OVER"
    ],
    "K22": [
      "W",
      "ROLL_OVER",
      "ROLL_OVER",
      "ROLL_OVER"
    ],
    "K09": [
      "F9",
      "ROLL_OVER",
      "ROLL_OVER",
      "ROLL_OVER"
    ]
  },
  "key_leds": {
    "K19": null,
    "K3A": null,
    "K56": null,
    "K48": null,
    "K53": null,
    "K10": null,
    "K16": null,
    "K24": null,
    "K28": null,
    "K1B": null,
    "K1D": null,
    "K5A": null,
    "K25": null,
    "K45": null,
    "K04": null,
    "K51": null,
    "K23": null,
    "K3B": null,
    "K06": null,
    "K26": null,
    "K1A": null,
    "K0A": null,
    "K34": null,
    "K52": null,
    "K36": null,
    "K2E": null,
    "K35": null,
    "K2A": null,
    "K18": null,
    "K11": null,
    "K44": null,
    "K01": null,
    "K05": null,
    "K40": null,
    "K42": null,
    "K32": null,
    "K4B": null,
    "K57": null,
    "K00": null,
    "K1E": null,
    "K17": null,
    "K2C": null,
    "K3C": null,
    "K33": null,
    "K37": null,
    "K08": null,
    "K59": null,
    "K03": null,
    "K1C": null,
    "K14": null,
    "K58": null,
    "K2B": null,
    "K39": null,
    "K47": null,
    "K20": null,
    "K09": null,
    "K30": null,
    "K0E": null,
    "K07": null,
    "K13": null,
    "K54": null,
    "K50": null,
    "K29": null,
    "K4C": null,
    "K2D": null,
    "K46": null,
    "K49": null,
    "K3D": null,
    "K43": null,
    "K15": null,
    "K0B": null,
    "K4A": null,
    "K38": null,
    "K21": null,
    "K41": null,
    "K12": null,
    "K02": null,
    "K31": null,
    "K55": null,
    "K22": null,
    "K5B": null,
    "K0C": null,
    "K27": null,
    "K0D": null
  },
  "layers": [
    {
      "mode": [
        14,
        127
      ],
      "brightness": 176,
      "color": [
        142,
        255
      ]
    },
    {
      "mode": [
        13,
        127
      ],
      "brightness": 176,
      "color": [
        142,
        255
      ]
    },
    {
      "mode": [
        13,
        127
      ],
      "brightness": 176,
      "color": [
        142,
        255
      ]
    },
    {
      "mode": [
        13,
        127
      ],
      "brightness": 176,
      "color": [
        142,
        255
      ]
    }
  ]
}
```

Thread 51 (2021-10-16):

Can the diameter of the through hole be adjusted from 0.40mm to 0.45mm?

zhangguanzhang, 2021-10-16:
Under the technology of most countries, the two sizes of 0.40mm and 0.45mm are manufactured by factory pcb at two different prices.
Can the diameter of the through hole be adjusted from 0.40mm to 0.45mm?
@jackpot51 @dlharmon 😘

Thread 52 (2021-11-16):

Add caps lock led indicator

HEX0101, 2021-11-16:
Considering that keyboard has bunch of LEDs, it would be useful it keyboard changed color when caps lock is on.

hiruko-san, 2022-03-05:
I would add to this and suggest something like turn the LED into a different colour when Caps Lock is On.
eg. Layer 1 LED is White, when Caps Lock is On, the LED on the Caps Lock key would turn Green.
Or when Layer1 LED is Disabled, the LED would light up in Green when Caps Lock is On.

billpayne4x4, 2022-08-14:
It would be nice if there was a Caps Lock modifier to all the LED layers so you could set a different layer patter/color when the Caps Lock was down.

leviport, 2023-02-03:
>But I suppose this keyboard cannot get new features. I'm guessing it's a board with hardware features, where software can just fill up some registers to map keys. I don't think a feature like this can be added now. Maybe in V2, which I'll never buy since this keyboard was already expensive enough.

The firmware controls everything, not just keymapping. This is probably something that could be implemented in firmware, it's just super tricky to do, since you somehow have to account for whatever color the LED was previously, and whether or not it is changing because of an animation.

The firmware is here, if anyone wants to give it a try: https://github.com/system76/qmk_firmware/

Just be careful not to brick it with a firmware flash while you tinker.

taivlam, 2023-03-12:
Now that the Launch Heavy version has been out for a bit, I'd also like to
suggest adding an LED indicator for the <kbd>Num Lock</kbd> key - since in the
meantime I've been using the [Lock Keys](https://extensions.gnome.org/extension/36/lock-keys/)
extension for GNOME to make sure I don't have the <kbd>Caps Lock</kbd> on by
accident or have the <kbd>Num Lock</kbd> key off by accident.

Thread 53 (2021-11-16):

Selma test program

CaryHertert, 2021-11-16:
Launch's Selma test program removes keymap if the operator does not press the stop button after initiating the switch test.  Can we change this to a set duration that doesnt require input from the operator?  The physical  test takes 2 minutes.

leviport, 2022-11-02:
I believe this has been addressed

Closed 2022-11-02.

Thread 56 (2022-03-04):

Layer 2 get's locked on when using Access Layer 2 key

ahoneybun, 2022-03-04:
Issue:

When using the attached layout and tapping the Access Layer 2 key multiple times in a row the lights can get stuck like in this video:

https://user-images.githubusercontent.com/4884946/156797924-43564511-e847-4ce7-86a0-428e8ad6f548.mp4

[launch_layout_1.zip](https://github.com/system76/launch/files/8187169/launch_layout_1.zip)

hiruko-san, 2022-03-10:
the issue usually happens when I'm adjusting my volume, so it's just one single key press on the "access layer 2" / "Fn" key, or to be precise, a single press & hold, while I adjust the volume with "+" or "-" or mute. It's random and purely based on chance when it happens.

I've also noticed this only happens if I don't have any lights on the first layer, (i.e. Layer 1 LED is completely disabled). For example, if I set Layer 1 LED to all white, Layer 2 to Blue for "bound keys only", I could not recreate this issue, it will always return to white LED.

gondolyr, 2022-03-21:
I'm glad I'm not the only one experiencing this issue.

I didn't get any responses in my previous filing here: https://github.com/system76/launch/issues/48

leviport, 2023-03-06:
This _might_ be fixed by https://github.com/system76/qmk_firmware/pull/34

andy0130tw, 2023-03-18:
@leviport I tried the provided PR, but it was not fixed.

zerobearing2, 2023-05-25:
having same issue

andy0130tw, 2025-04-19:
After years of usage, I have convinced myself that this lighting issue comes from some synchronization issue that may not be solvable.

Referring to the schematic diagram of this board, the LEDs are connected like a long strip. If you observe more lighting glitches, you will notice that the top row is more frequently glitched than others, and they are at the farther end of the LED strip. My theory is that the time duration pressing/releasing a key in succession is often too brief for the entire set of LEDs to react to the signal, and some signal are lost afterwards.

I am not a hardcore keyboard guy (even not a hardware guy), so if someone can help elaborate on this, I will greatly appreciate.

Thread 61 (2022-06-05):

My keyboard does not work

rpayanm, 2022-06-05:
My keyboard has been working perfectly for a year. Yesterday it was working fine and today it does not work, I have not hit it or dropped it. I tested it on another computer and it did not work, also I changed the USB cable and it did not work either.
The dmesg command does not show anything when I plug in/off.
Any thoughts or recommendations?

leviport, 2022-06-06:
@rpayanm it sounds like you need to open a support ticket. The support team will be able to take care of you. Github issues are for bug tracking, and the support team generally doesn't hang around here often.

Be sure to let them know which cable you're using, whether the RGB LEDs are working, and the OSes of the computers you tested it on.

Closed 2022-06-06.

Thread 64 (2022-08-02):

Firmware Update Issue for Launch

Titor8115, 2022-08-02:
I'm currently on Fedora 36, And was trying to update the firmware of the Launch Keyboard. When I'm doing manual firmware update (the keyboard never flashes UNLOCK pattern since I got it half year ago even on PopOs) through the Firmware software and was giving a notification to unlock the keyboard using `Fn` + `Esc`. However, When I unlocked the keyboard, all the updates options simply disappear. (System76 Keyboard Configuration Software also lose detection of the keyboard). I'm currently flashing the keyboard using repository forked from QMK repo (not this one), if that has anything related to this problem. I also recompiled with both `BOOTMAGIC` on and off and resetting the keyboard via System76 Keyboard configuration software, but the same problem remains.
Below are related information of the device and the issue described above.

Before Unlock
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

After Unlock
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

leviport, 2022-08-02:
I would recommend flashing from our QMK fork and seeing if that helps: https://github.com/system76/qmk_firmware/blob/master/keyboards/system76/launch_1/README.md

Also, can you please post the launch_1 details from the output of `fwupdmgr get-devices`?

jecassis, 2022-08-05:
I think I implemented a solution to this problem for the upstream repository in this [PR](https://github.com/qmk/qmk_firmware/pull/17916). From the description, it appears that instead of "unlocking" and waiting for the updater to send the HID command to go into the bootloader, it jumps straight into it--from the System76 VID before unlock and the Atmel VID after unlock. The keyboard does not acknowledge the command in any case, so the updater just sees a new device and likely does not go into its firmware flashing routines.

Note that in the upstream firmware, `Fn+Esc` is mapped to the `QK_BOOTLOADER` keycode in the default keymap. The configurator/LVFS uses HID and so the process is to is why I think System76 has added `LCtrl+Rctrl+Esc` to put it into that mode independently of the QMK defaults. Most of this is just speculation.

Titor8115, 2022-08-05:
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

I will send update you with the output of `fwupdmgr` as soon as I return to my workstation (should be Tomorrow)

leviport, 2022-08-05:
>is why I think System76 has added LCtrl+Rctrl+Esc to put it into that mode independently of the QMK defaults

Partially that, but also because we had to figure out how to unlock a Launch Lite, since Fn+Esc on Lite = tilde/backtick

Titor8115, 2022-08-11:
@leviport
Sorry for the late reply, Here is the output of `fwupdmgr get-devices` for the keyboard
```
├─Launch Configurable Keyboard (launch 1):
│     Device ID:          29627b6877d3b89cccee135287435fde986fee98
│     Current version:    0.17.0-92-g48635d-dirty
│     Vendor:             System76 (USB:0x3384)
│     GUIDs:              b2cfb86e-dacd-5663-83e6-58059831ab6d
│                         af6272df-30f2-5067-ae05-201e69cd08a5 ← USB\VID_3384&PID_0001
│                         7549de75-189b-5fa6-911a-c9f5d127dc28 ← USB\VID_3384&PID_0001&REV_0001
│     Device Flags:       • Updatable
│                         • Supported on remote server
│                         • Unsigned Payload
```

leviport, 2022-08-11:
Was that after flashing from our QMK fork?

Titor8115, 2022-08-11:
@leviport The previous output was not using this fork of the qmk_firmware. But using this fork for flashing seemed to resolve the issue and firmware had been updated to the newest `0.7.103-4026-g7fd2f5` version.
`├─Launch Configurable Keyboard (launch 1):
│     Device ID:          29627b6877d3b89cccee135287435fde986fee98
│     Current version:    0.7.103-4026-g7fd2f5
│     Vendor:             System76 (USB:0x3384)
│     GUIDs:              b2cfb86e-dacd-5663-83e6-58059831ab6d
│                         af6272df-30f2-5067-ae05-201e69cd08a5 ← USB\VID_3384&PID_0001
│                         7549de75-189b-5fa6-911a-c9f5d127dc28 ← USB\VID_3384&PID_0001&REV_0001
│     Device Flags:       • Updatable
│                         • Supported on remote server
│                         • Unsigned Payload
`

Question not related to current issue. What is the Macro for `Switch to layer #` for launch_1? the QMK macro `TOGGLE_LAYER` doesn't seem to work.

leviport, 2022-08-11:
>Question not related to current issue. What is the Macro for Switch to layer # for launch_1? the QMK macro TOGGLE_LAYER doesn't seem to work.

If you're making firmware manually, it's `TO(#)` . My layer 3 has an example of using TO(): https://github.com/system76/qmk_firmware/blob/master/keyboards/system76/launch_1/keymaps/levi/keymap.c

Titor8115, 2022-08-11:
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

I see. Thanks for everything. Ill close this issue since all the problems have been resolved

Closed 2022-08-11.

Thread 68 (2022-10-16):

Custom Keycaps

Logic-gate, 2022-10-16:
Hey,

This isn't an issue, just a shout out for anyone looking for a template in case they want to print some custom keycaps.

https://github.com/Logic-gate/Launch_kb_svg

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

Enjoy.

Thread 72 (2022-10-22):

Feature Request: Toggle NKRO On/Off

XuhengLi, 2022-10-22:
Hi,

I wonder if it's possible to support the dynamic toggling of NKRO.

This is an important feature for multi-language macOS users because macOS has problems handling `CAPS` when NKRO is enabled.

More specifically, macOS has a feature that supports switching the input method from and to U.S. by a short press of `CAPS,` and a long press of `CAPS` will lock all input to uppercase. But when NKRO is enabled, a short press of `CAPS` will be interpreted(by macOS) as both a short and long press, and thus macOS will switch the input method and then lock the caps.

More discussion can be found in an issue in the upstream qmk_firmware repo: https://github.com/qmk/qmk_firmware/issues/15178.

I build the firmware on my own to disable NKRO in [keyboards/system76/launch_1/rules.mk](https://github.com/system76/qmk_firmware/blob/master/keyboards/system76/launch_1/rules.mk), but this will also disable `system76_ec_eeprom_op` in [keyboards/system76/system76_ec.c](https://github.com/system76/qmk_firmware/blob/master/keyboards/system76/system76_ec.c) because `eeprom_update_block/eeprom_read_block` is only defined when `ENABLE_NKRO = yes`. Disabling `system76_ec_eeprom_op` will make the configurator unable to save the LED configuration(but the keymap is fine).

 Based on the qmk_firmware wiki, NKRO should be able to be disabled dynamically: https://github.com/tmk/tmk_keyboard/wiki/FAQ#nkro-doesnt-work. But the `Magic` N command doesn't seem to work on the launch firmware.

If it is possible to support this feature?

Cheers!

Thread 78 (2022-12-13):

Minor firmware LED bug

hendersj, 2022-12-13:
Just got my Launch Heavy yesterday and I love it - getting used to the keys being in a different place for home/pgup/pgdn/end etc is taking a little time (but it's < 24 hours since I unboxed and started using it, so I expect I'll get there easily).

One thing I noticed is when switching the LEDs in the keyboard configurator from "per-layer solid color" to "bound keys only", the default layer 1 keyboard layout loses the LED over the "Up" key.  The key is bound, but it doesn't show as bound.

I just tested this by assigning something to it other than "reuse" in layer 2, and I see the same behavior.

In all other LED configurations, the LED works as expected - just the bound keys one where it turns off no matter what the key is set to do.

LMK what info is needed - should be easy to duplicate, I believe.

leviport, 2022-12-13:
Thanks for the report! I've been able to confirm this one as well. It's probably something that has to be fixed in firmware, so I'll move this to our QMK fork repo.

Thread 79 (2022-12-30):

Switch back to USB 3.2 Gen 2 (USB7206)

jacobgkau, 2022-12-30:
Wanted to record this on a tracker.

We changed from the USB7206 (3.2 Gen 2) to USB7006 (3.2 Gen 1) for Launch earlier this year because no 72x6 parts were in stock. Both DigiKey and Mouser now have thousands of USB7206 in stock at this point. The closest-matching part is USB7206CT/KDX, which @dlharmon confirmed should require no electrical changes (only possible firmware changes.)

- DigiKey (currently 2,959 in stock): https://www.digikey.com/en/products/detail/microchip-technology/USB7206CT-KDX/14325438
- Mouser (currently 7,356 in stock): https://www.mouser.com/ProductDetail/Microchip-Technology-Atmel/USB7206CT-KDX?qs=DRkmTr78QAQ6i3MTxEbtog%3D%3D

As the intention was to undo the downgrade once stock became available again, it would be good to switch back to Gen 2 with this available 7206 part (or at least get the change staged for when we run out of our current 7006 stock.)

Closed 2023-08-25.

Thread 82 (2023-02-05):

PS5 recognizes Launch keyboard but can't type

rigbyjacob, 2023-02-05:
The Launch is detected as a keyboard by the PlayStation 5 but keypresses don't seem to register on any input screens.

From limited research, any HID compliant keyboard should work fine, especially USB (most issues are with wireless devices)

Since the Launch is open source, wondering what changes might be required to make this setup work?

leviport, 2023-02-06:
It's possible that the rebase might improve the situation: https://github.com/system76/qmk_firmware/pull/31

Unfortunately I don't have a PS5 to test with though.

rigbyjacob, 2023-02-06:
Is it possible to update the firmware from Mac OS?

A quick reading of instructions seems to imply need Pop_OS (which i don't have access to at the moment, that computer is in another kingdom)

leviport, 2023-02-06:
To update from that PR, you'll be building from source and flashing manually. I believe this is possible to do from macOS, but I don't have enough experience with macOS to be able to help.

NuclearArmedHog, 2023-07-31:
Did yall ever make it work on the PS5?

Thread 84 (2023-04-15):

Feature Request: Consider a tap vs hold option

Vashinator, 2023-04-15:
This isn't as big of a deal to me as #83
But it would be a nice feature to be able to have a tap vs held option when configuring a key.

Some ideas I've seen:
- having caps when a letter is held down (though that may be a keyboard wide setting).
- Doing more with caps lock by using the tap to be standard caps lock and hold to be a combo of modifier keys.
- Using the Fn key, a tap switches the layer until it's tapped again,  a hold only has the layer active while it's being held.

leviport, 2023-04-17:
Duplicate of https://github.com/pop-os/keyboard-configurator/issues/64

Since Launch uses QMK firmware, this is already supported, but firmware must be [manually customized and flashed](https://github.com/system76/qmk_firmware/blob/master/keyboards/system76/launch_1/readme.md), rather than mapped using the Configurator. Support for more advanced functionality, including mod-tap is [currently being worked on](https://github.com/pop-os/keyboard-configurator/issues/64).

Closed 2023-04-17.

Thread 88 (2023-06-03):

Issue updating Launch Heavy firmware from 0.7.103 to 0.7.104

g-dg, 2023-06-03:
I'm having an issue updating my Launch Heavy from 0.7.103 to 0.7.104 using fwupd (1.8.14).

It complains about "writing firmware not supported by device" whether I press the unlock key combination before or after running the update, and whether I have anything else plugged into the keyboard's USB hub or not. It still fails if I reset the keyboard's configuration.

I notice that the update message says "Fixes bootloader jump for FWUPD, which should fix some users being unable to install firmware updates." Could this be what is happening, and if so, how do I fix it?

```
$ sudo fwupdmgr update
Devices with no available firmware updates:
 • Keyboard
 • Keyboard
 • SSD 970 EVO Plus 1TB
 • System Firmware
 • UMC404HD 192k
 • Unifying Receiver
 • WD Blue SA510 2.5 1000GB
╔══════════════════════════════════════════════════════════════════════════════╗
║ Upgrade Launch Heavy Configurable Keyboard (launch heavy 1) from             ║
║ 0.7.103-4038-g223cd2 to 0.7.104-188-g7a655e530b?                             ║
╠══════════════════════════════════════════════════════════════════════════════╣
║ Fixes bootloader jump for FWUPD, which should fix some users being unable    ║
║ to install firmware updates.                                                 ║
║                                                                              ║
║ Launch Heavy Configurable Keyboard (launch heavy 1) and all connected        ║
║ devices may not be usable while updating.                                    ║
╚══════════════════════════════════════════════════════════════════════════════╝
Perform operation? [Y|n]:
Action Required: To ensure you have physical access, Launch Heavy Configurable Keyboard (launch heavy 1) needs to be manually unlocked. Please press Left Ctrl+Right Ctrl+Esc to unlock and re-run the update.
Writing…                 [***********                            ] Less than one minute remaining…
writing firmware not supported by device
```

leviport, 2023-06-05:
That does sound like the bug that was fixed by that update. A rather nasty bug, since it makes it more difficult to install the fix. Fortunately there is a way to update via DFU that circumvents fwupd: https://support.system76.com/articles/launch_2-firmware-update

After this update, fwupd will work as expected.

g-dg, 2023-06-05:
Thanks for pointing me in the right direction. I eventually managed to get it working.

I tried using both an AUR build and a manual build (since the AppImage for the keyboard configurator with the new firmware doesn't seem to be available from the repo releases page). Those failed with a message about `/var/lib/system76-keyboard-configurator/system76_launch_heavy_1_default.hex` missing, so I copied the hex files in the `data` directory of the keyboard configurator source code to that location, but then it failed with a message about the flash not being empty.

Then I looked at the keyboard configurator source code to see if I could find the `dfu-programmer` command. I found it in [src/configurator_app.rs](https://github.com/pop-os/keyboard-configurator/blob/master/src/configurator_app.rs). I then copied the command (make sure it's the correct one for your keyboard!) and added `--force` to bypass the empty flash check. Then, after issuing the flash and reset commands, the keyboard is now on the latest firmware and reinstalling the latest firmware with fwupd now works!

Unfortunately, I found an issue with remapping layer access keys from the factory default in the configurator causing layers to get stuck with the new firmware, but that's an issue for the keyboard-configurator repo. Fortunately holding ESC while plugging in the keyboard resets it nicely.

leviport, 2023-06-05:
Ah sorry, I just assumed you were on Pop. This can also be done by manually flashing QMK firmware: https://github.com/system76/qmk_firmware/tree/master/keyboards/system76/launch_heavy_1

We also discovered the configurator issue today, and we have a PR that should fix it open here: https://github.com/pop-os/keyboard-configurator/pull/189

Turns out this bug has become quite the headache for us here, but I think we're pretty close to putting it all behind us.

leviport, 2023-06-07:
The latest release also fixes the appimage build: https://github.com/pop-os/keyboard-configurator/releases/tag/v1.3.6

I believe that should square things away, so I'm going to close this. Let me know if there is any more trouble and we can reopen it.

Closed 2023-06-07.

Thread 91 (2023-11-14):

[Request] to Machine bottom so downward tilt is possible.

LennonConson, 2023-11-14:
The magnetic tilt bar (PN-000174) can only be applied for upward tile. It would be nice if a downward tilt could be applied to the front for a down ward tile.

To see what I am talking about see this reddit post [https://www.reddit.com/r/Ergonomics/comments/l2d9w5/reverse_tilt_keyboards_theory/
](https://www.reddit.com/r/Ergonomics/comments/l2d9w5/reverse_tilt_keyboards_theory/
)

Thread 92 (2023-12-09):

Launch Heavy (1): platforms/avr/drivers/ws2812_bitbang.c:41:18: error: ‘WS2812_DI_PIN’ undeclared

jojo2357, 2023-12-09:
Solved by adding

`#    define WS2812_DI_PIN RGB_DI_PIN`

to `config.h`.

Seems like the new version of the led driver changed the macro name and that was not made to `main` here

jojo2357, 2023-12-09:
Apologies, this is the wrong repo.

Closed 2023-12-09.

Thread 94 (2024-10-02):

Add music/audio controls

liam-clink, 2024-10-02:
A common feature on keyboards is a volume knob, play/pause, and next/previous buttons. This is the primary thing turning me off to buying one of these keyboards, so I hope you implement this, as I love the concept otherwise and want to support it.

leviport, 2024-10-14:
Launch Heavy has play/pause, previous track, and next track above the tenkey. While it is not bound by default on Launch and Launch Lite, they (as well as volume control keys) can easily be bound with the System76 Keyboard Configurator application: https://github.com/pop-os/keyboard-configurator/

liam-clink, 2024-10-14:
My main and first point was the volume knob, which it does not have. Having to switch out of a game or something in order to change the volume is quite inconvenient.

jacobgkau, 2024-10-14:
While it's not a knob (which would add significant manufacturing complexity and would not be as configurable), you can assign Volume Up and Volume Down to any key (or Fn + key) using the Keyboard Configurator. If you do that, you won't have to switch out of a game or move the mouse to adjust the volume.

Closed 2024-10-14.

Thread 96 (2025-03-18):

OS says launch keyboard is pulling to much power.

craigcampbell, 2025-03-18:
I'm not finding much in the way on the support articles or here. Does anyone else have this issue? This is happening with nothing else in the ports.

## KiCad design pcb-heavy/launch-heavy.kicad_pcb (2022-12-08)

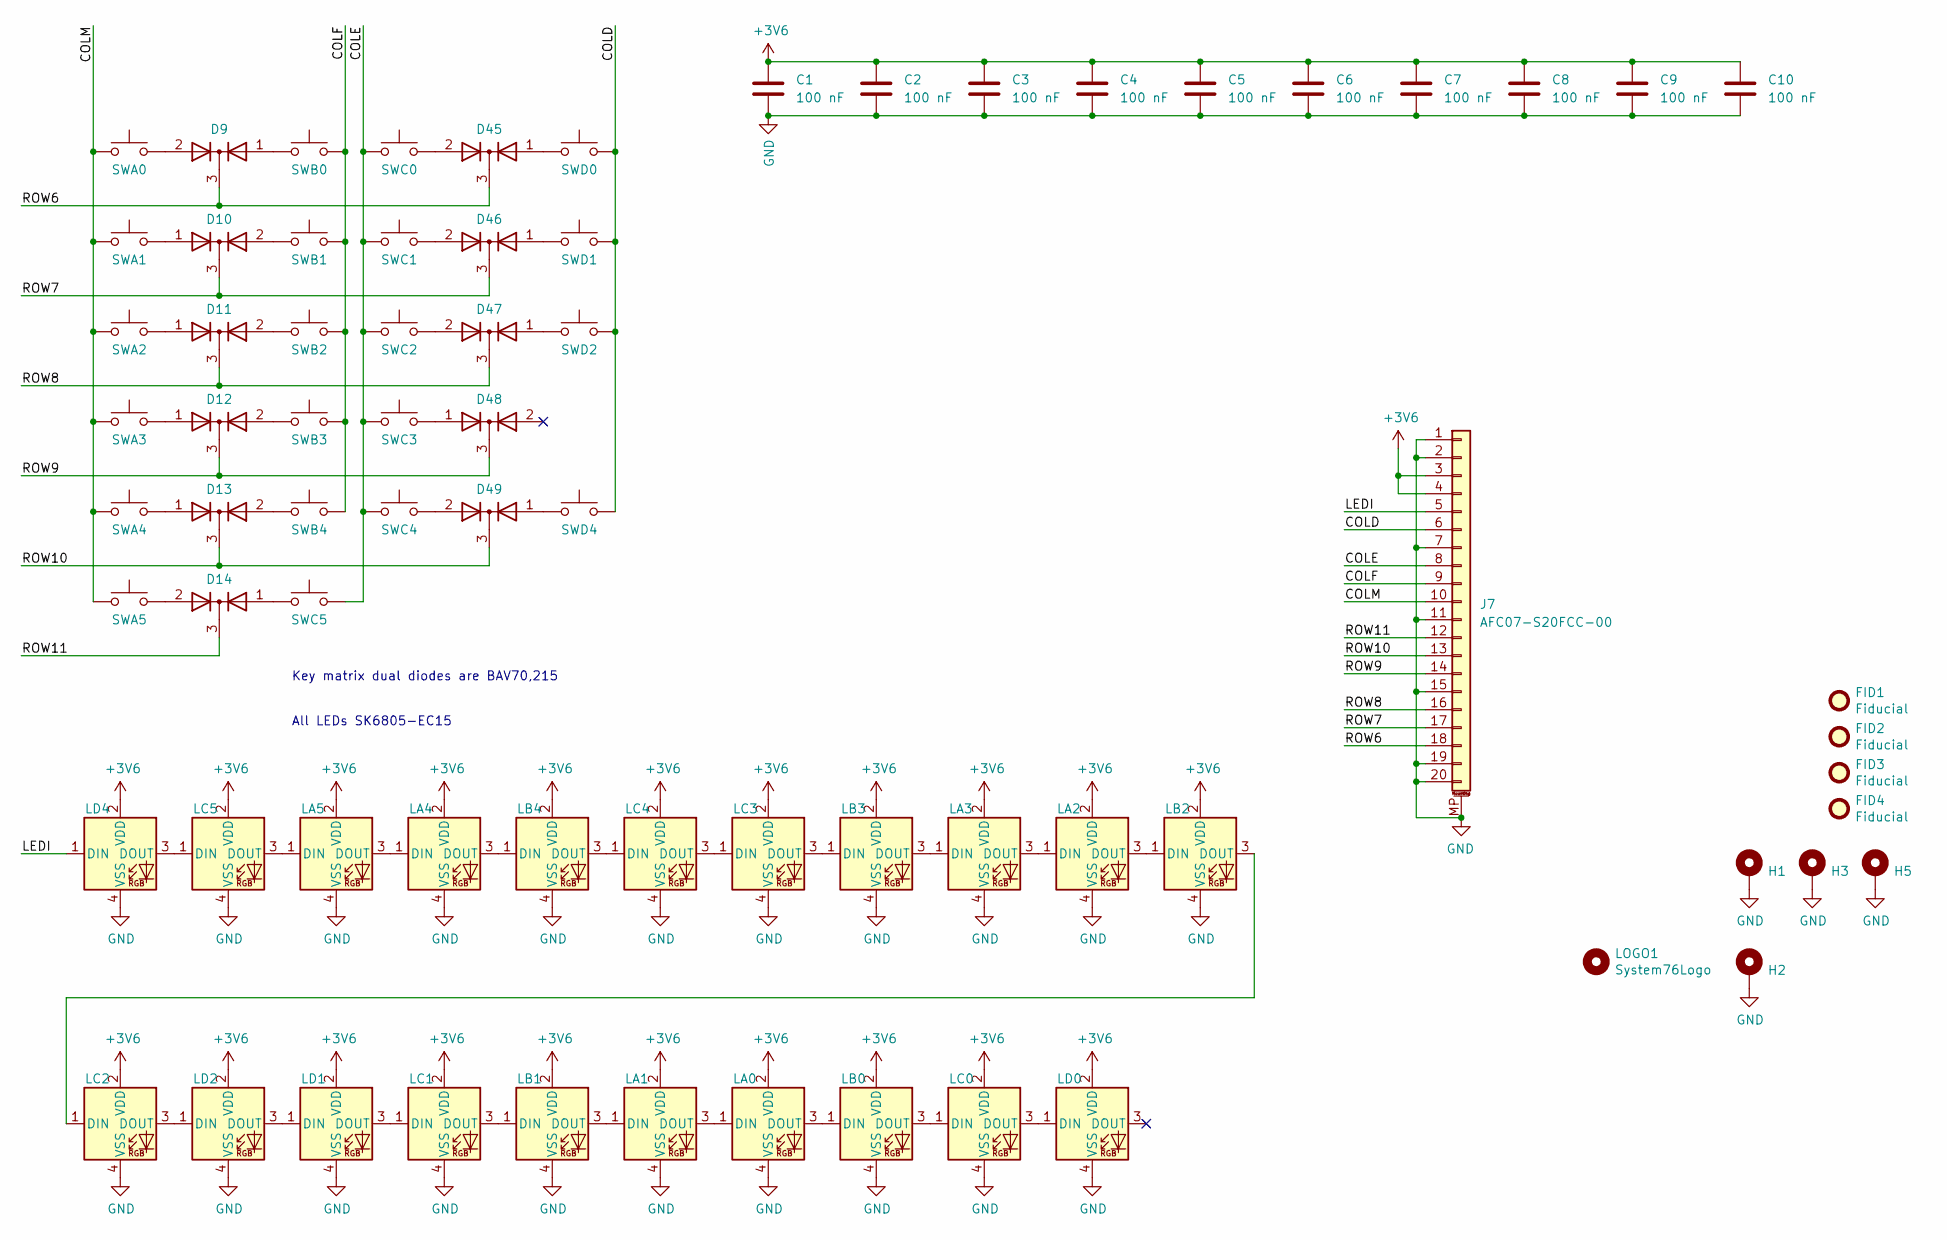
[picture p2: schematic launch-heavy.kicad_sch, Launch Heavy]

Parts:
C1, C2, C3, C4, C5, C6, C7, C8, C9, C10: 100 nF; C_0603_1608Metric
D9, D10, D11, D12, D13, D14, D45, D46, D47, D48, D49: BAV70,215; SOT-23
FID1, FID2, FID3, FID4: Fiducial; Fiducial_0.75mm_Mask1.5mm
H1, H2, H3, H5: MountingHole_Pad; MountingHole
J7: AFC07-S20FCC-00
LA0, LA1, LA2, LA3, LA4, LA5: SK6805-EC15; LED_SK6805-EC15
LB0, LB1, LB2, LB3, LB4: SK6805-EC15; LED_SK6805-EC15
LC0, LC1, LC2, LC3, LC4, LC5: SK6805-EC15; LED_SK6805-EC15
LD0, LD1, LD2, LD4: SK6805-EC15; LED_SK6805-EC15
LOGO1: System76Logo; System76
SWA0, SWA1, SWA2, SWA3, SWA4, SWA5: CPG151101S11; Kailh_socket_MX
SWB0, SWB1, SWB2, SWB3, SWB4: CPG151101S11; Kailh_socket_MX
SWC0, SWC1, SWC2, SWC3, SWC4, SWC5: CPG151101S11; Kailh_socket_MX
SWD0, SWD1, SWD2, SWD4: CPG151101S11; Kailh_socket_MX

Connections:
+3V6: C1.2, C2.2, C3.2, C4.2, C5.2, C6.2, C7.2, C8.2, C9.2, C10.2, J7.3, J7.4, LA0.2 (VDD), LA1.2 (VDD), LA2.2 (VDD), LA3.2 (VDD), LA4.2 (VDD), LA5.2 (VDD), LB0.2 (VDD), LB1.2 (VDD), LB2.2 (VDD), LB3.2 (VDD), LB4.2 (VDD), LC0.2 (VDD), LC1.2 (VDD), LC2.2 (VDD), LC3.2 (VDD), LC4.2 (VDD), LC5.2 (VDD), LD0.2 (VDD), LD1.2 (VDD), LD2.2 (VDD), LD4.2 (VDD)
/COLD: J7.6, SWD0.1, SWD1.1, SWD2.1, SWD4.1
/COLE: J7.8, SWC0.1, SWC1.1, SWC2.1, SWC3.1, SWC4.1, SWC5.1
/COLF: J7.9, SWB0.1, SWB1.1, SWB2.1, SWB3.1, SWB4.1
/COLM: J7.10, SWA0.1, SWA1.1, SWA2.1, SWA3.1, SWA4.1, SWA5.1
/LEDI: J7.5, LD4.1 (DIN)
/ROW6: D9.3 (K), D45.3 (K), J7.18
/ROW7: D10.3 (K), D46.3 (K), J7.17
/ROW8: D11.3 (K), D47.3 (K), J7.16
/ROW9: D12.3 (K), D48.3 (K), J7.14
/ROW10: D13.3 (K), D49.3 (K), J7.13
/ROW11: D14.3 (K), J7.12
GND: C1.1, C2.1, C3.1, C4.1, C5.1, C6.1, C7.1, C8.1, C9.1, C10.1, H1.1, H2.1, H3.1, H5.1, J7.1, J7.2, J7.7, J7.11, J7.15, J7.19, J7.20, J7.MP (MountPin), LA0.4 (VSS), LA1.4 (VSS), LA2.4 (VSS), LA3.4 (VSS), LA4.4 (VSS), LA5.4 (VSS), LB0.4 (VSS), LB1.4 (VSS), LB2.4 (VSS), LB3.4 (VSS), LB4.4 (VSS), LC0.4 (VSS), LC1.4 (VSS), LC2.4 (VSS), LC3.4 (VSS), LC4.4 (VSS), LC5.4 (VSS), LD0.4 (VSS), LD1.4 (VSS), LD2.4 (VSS), LD4.4 (VSS)
unnamed: D9.1 (A), SWB0.2
unnamed: D9.2 (A), SWA0.2
unnamed: D10.1 (A), SWA1.2
unnamed: D10.2 (A), SWB1.2
unnamed: D11.1 (A), SWA2.2
unnamed: D11.2 (A), SWB2.2
unnamed: D12.1 (A), SWA3.2
unnamed: D12.2 (A), SWB3.2
unnamed: D13.1 (A), SWA4.2
unnamed: D13.2 (A), SWB4.2
unnamed: D14.1 (A), SWC5.2
unnamed: D14.2 (A), SWA5.2
unnamed: D45.1 (A), SWD0.2
unnamed: D45.2 (A), SWC0.2
unnamed: D46.1 (A), SWD1.2
unnamed: D46.2 (A), SWC1.2
unnamed: D47.1 (A), SWD2.2
unnamed: D47.2 (A), SWC2.2
unnamed: D48.1 (A), SWC3.2
unnamed: D49.1 (A), SWD4.2
unnamed: D49.2 (A), SWC4.2
unnamed: LA0.1 (DIN), LA1.3 (DOUT)
unnamed: LA0.3 (DOUT), LB0.1 (DIN)
unnamed: LA1.1 (DIN), LB1.3 (DOUT)
unnamed: LA2.1 (DIN), LA3.3 (DOUT)
unnamed: LA2.3 (DOUT), LB2.1 (DIN)
unnamed: LA3.1 (DIN), LB3.3 (DOUT)
unnamed: LA4.1 (DIN), LA5.3 (DOUT)
unnamed: LA4.3 (DOUT), LB4.1 (DIN)
unnamed: LA5.1 (DIN), LC5.3 (DOUT)
unnamed: LB0.3 (DOUT), LC0.1 (DIN)
unnamed: LB1.1 (DIN), LC1.3 (DOUT)
unnamed: LB2.3 (DOUT), LC2.1 (DIN)
unnamed: LB3.1 (DIN), LC3.3 (DOUT)
unnamed: LB4.3 (DOUT), LC4.1 (DIN)
unnamed: LC0.3 (DOUT), LD0.1 (DIN)
unnamed: LC1.1 (DIN), LD1.3 (DOUT)
unnamed: LC2.3 (DOUT), LD2.1 (DIN)
unnamed: LC3.1 (DIN), LC4.3 (DOUT)
unnamed: LC5.1 (DIN), LD4.3 (DOUT)
unnamed: LD1.1 (DIN), LD2.3 (DOUT)

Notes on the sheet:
Key matrix dual diodes are BAV70,215
All LEDs SK6805-EC15

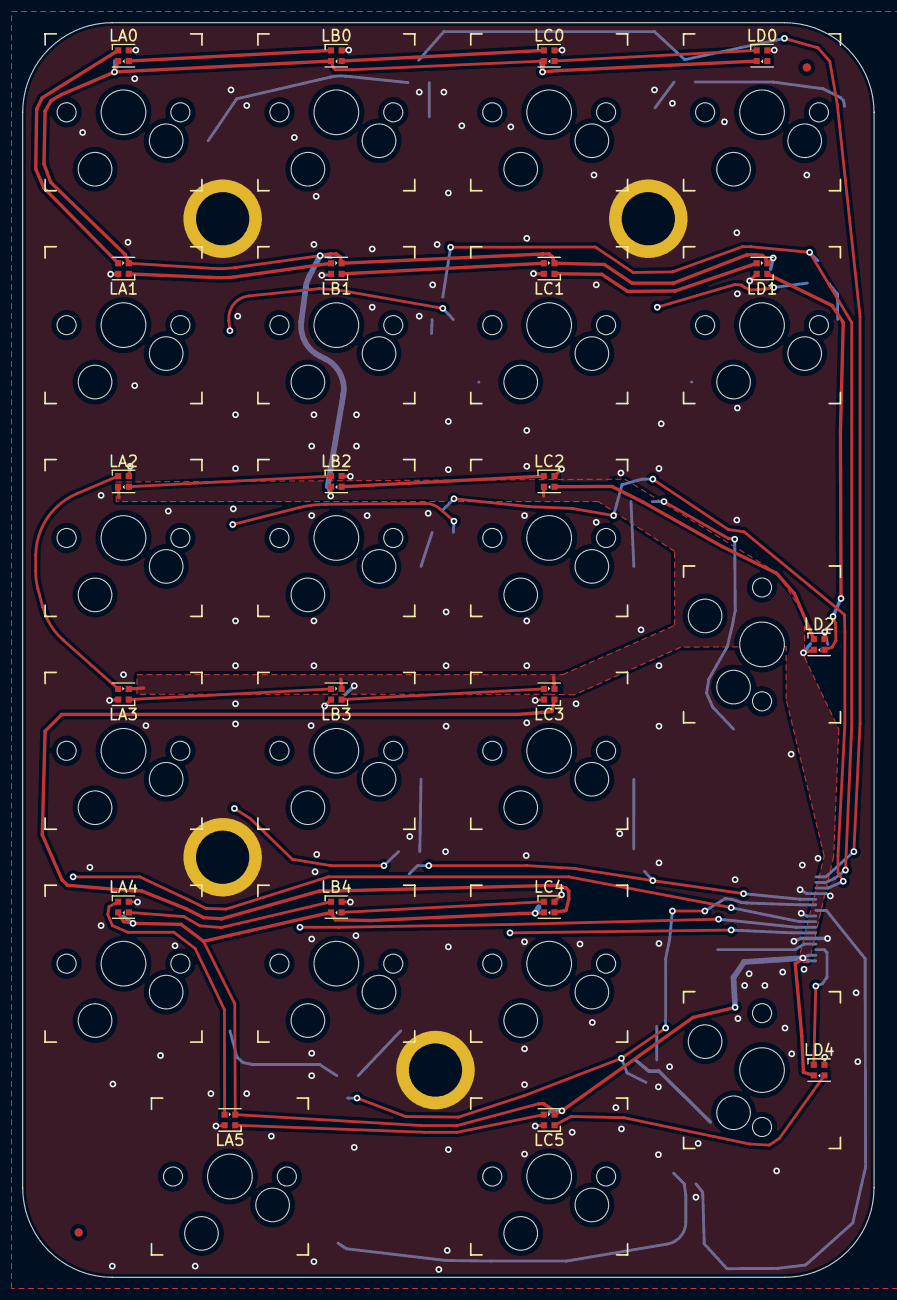
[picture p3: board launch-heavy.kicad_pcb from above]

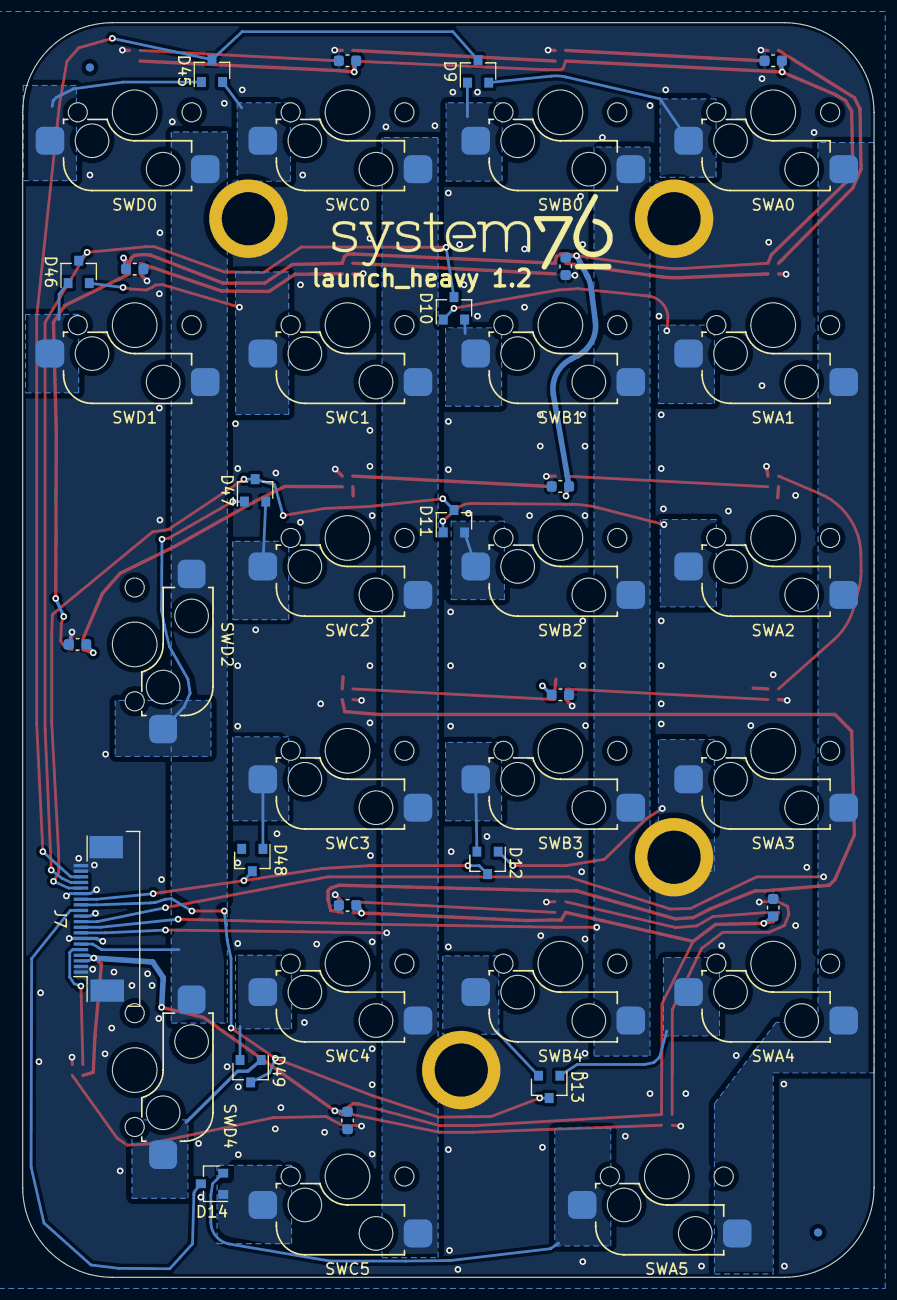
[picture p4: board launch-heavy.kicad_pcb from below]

Board: 2 copper layers, 76.0 x 112.0 mm, 73 parts (46 on the bottom side), 54 nets.

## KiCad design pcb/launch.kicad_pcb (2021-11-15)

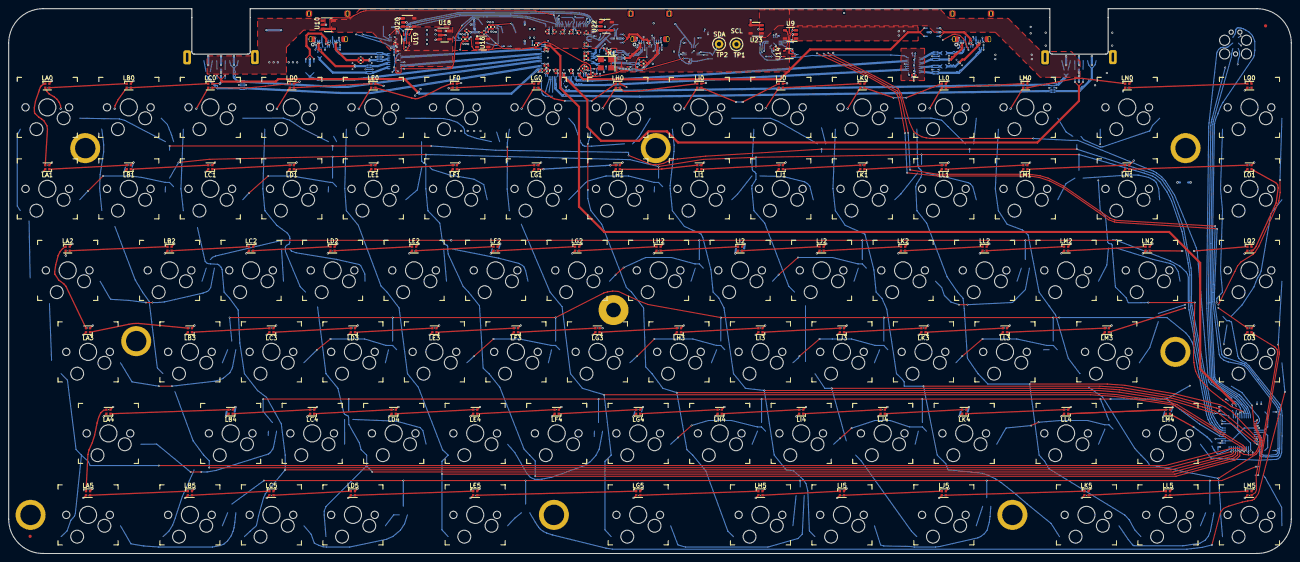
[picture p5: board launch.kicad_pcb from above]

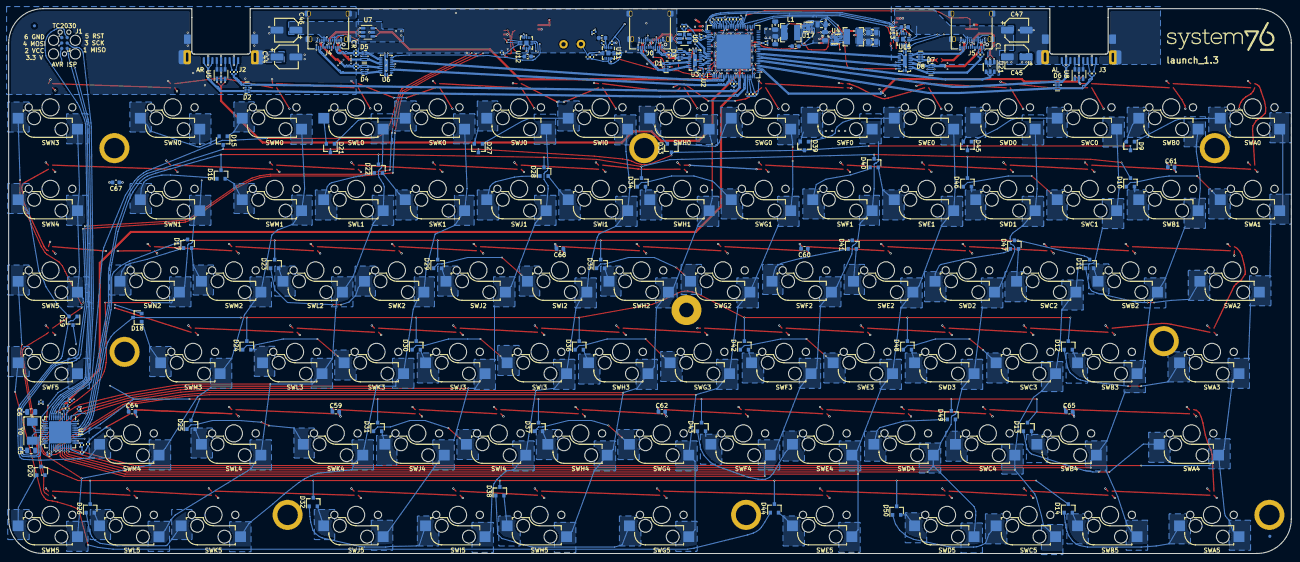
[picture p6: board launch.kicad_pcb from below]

Board: 4 copper layers, 299.0 x 127.0 mm, 372 parts (229 on the bottom side), 337 nets.

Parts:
C0, C1, C2, C3, C4, C8, C9, C10, C11, C12, C13, C14, C15, C16, C17, C18, C19, C20, C21, C22, C23, C24, C28, C29, C30, C31, C36, C37, C38, C39, C40, C41, C42, C43, C51, C52, C53, C54, C55, C56, C57, C58, C63: 0.1uF; C_0402_1005Metric
C5, C6: 22pF; C_0805_2012Metric
C7: 1 nF; C_0402_1005Metric
C25, C26, C27, C33, C59, C60, C61, C62, C64, C65, C66, C67: 2.2 uF; C_0603_1608Metric
C32, C34, C35, C48, C49, C50: 22 uF; C_0805_2012Metric
C44, C45, C46, C47: APXF6R3ARA151ME40G; CP_Elec_5x3.9
C68, C69: 330 pF; C_0402_1005Metric
D1, D2, D3, D4, D5, D6, D7, D8: PUSB3FR4Z; DFN-10_1x2.5mm_P0.5mm
D9, D10, D11, D12, D13, D14, D15, D16, D17, D18, D19, D20, D21, D22, D23, D24, D25, D26, D27, D28, D29, D30, D31, D32, D33, D34, D35, D36, D37, D38, D39, D40, D41, D42, D43, D44, D45, D46, D47, D48, D49, D50: BAV70,215; SOT-23
FID1, FID2, FID3, FID4: Fiducial; Fiducial_0.75mm_Mask1.5mm
H1, H2, H3, H4, H5, H6, H7, H8, H9: MountingHole_Pad; MountingHole
J0, J4, J5: 12401598E4#2A; USB_C_Receptacle_Amphenol_12401610E4-2A
J1: DNP; Tag-Connect_TC2030-IDC-FP_2x03_P1.27mm_Vertical
J2, J3: 1003-002-01100; USB3_A_CnC_Tech_1003-002-01100
L1, L2: SRN4018TA-2R2M; L_Bourns-SRN4018
LA0, LA1, LA2, LA3, LA4, LA5: SK6805-EC15; LED_SK6805-EC15
LB0, LB1, LB2, LB3, LB4, LB5: SK6805-EC15; LED_SK6805-EC15
LC0, LC1, LC2, LC3, LC4, LC5: SK6805-EC15; LED_SK6805-EC15
LD0, LD1, LD2, LD3, LD4, LD5: SK6805-EC15; LED_SK6805-EC15
LE0, LE1, LE2, LE3, LE4, LE5: SK6805-EC15; LED_SK6805-EC15
LF0, LF1, LF2, LF3, LF4: SK6805-EC15; LED_SK6805-EC15
LG0, LG1, LG2, LG3, LG4, LG5: SK6805-EC15; LED_SK6805-EC15
LH0, LH1, LH2, LH3, LH4, LH5: SK6805-EC15; LED_SK6805-EC15
LI0, LI1, LI2, LI3, LI4, LI5: SK6805-EC15; LED_SK6805-EC15
LJ0, LJ1, LJ2, LJ3, LJ4, LJ5: SK6805-EC15; LED_SK6805-EC15
LK0, LK1, LK2, LK3, LK4, LK5: SK6805-EC15; LED_SK6805-EC15
LL0, LL1, LL2, LL3, LL4, LL5: SK6805-EC15; LED_SK6805-EC15
LM0, LM1, LM2, LM3, LM4, LM5: SK6805-EC15; LED_SK6805-EC15
LN0, LN1, LN2: SK6805-EC15; LED_SK6805-EC15
LO0, LO1, LO2, LO3: SK6805-EC15; LED_SK6805-EC15
LOGO1: System76Logo; System76
R1: 12 k; R_0402_1005Metric
R2, R3: 22; R_0402_1005Metric
R4, R5, R6, R7, R8, R11, R15, R23, R26, R31, R32: 10 k; R_0402_1005Metric
R9, R10, R14: 9.1 k; R_0402_1005Metric
R12, R13, R19, R20: 200 k; R_0402_1005Metric
R16, R17, R29, R30: 100 k; R_0402_1005Metric
R18, R21: 43 k; R_0402_1005Metric
R22, R25, R28: 52.3 k; R_0402_1005Metric
R24, R33, R34: DNP; R_0402_1005Metric
R27: 499; R_0402_1005Metric
SWA0, SWA1, SWA2, SWA3, SWA4, SWA5: CPG151101S11; Kailh_socket_MX
SWB0, SWB1, SWB2, SWB3, SWB4, SWB5: CPG151101S11; Kailh_socket_MX
SWC0, SWC1, SWC2, SWC3, SWC4, SWC5: CPG151101S11; Kailh_socket_MX
SWD0, SWD1, SWD2, SWD3, SWD4, SWD5: CPG151101S11; Kailh_socket_MX
SWE0, SWE1, SWE2, SWE3, SWE4, SWE5: CPG151101S11; Kailh_socket_MX
SWF0, SWF1, SWF2, SWF3, SWF4, SWF5: CPG151101S11; Kailh_socket_MX
SWG0, SWG1, SWG2, SWG3, SWG4, SWG5: CPG151101S11; Kailh_socket_MX
SWH0, SWH1, SWH2, SWH3, SWH4, SWH5: CPG151101S11; Kailh_socket_MX
SWI0, SWI1, SWI2, SWI3, SWI4, SWI5: CPG151101S11; Kailh_socket_MX
SWJ0, SWJ1, SWJ2, SWJ3, SWJ4, SWJ5: CPG151101S11; Kailh_socket_MX
SWK0, SWK1, SWK2, SWK3, SWK4, SWK5: CPG151101S11; Kailh_socket_MX
SWL0, SWL1, SWL2, SWL3, SWL4, SWL5: CPG151101S11; Kailh_socket_MX
SWM0, SWM1, SWM2, SWM3, SWM4, SWM5: CPG151101S11; Kailh_socket_MX
SWN0, SWN1, SWN2, SWN3, SWN4, SWN5: CPG151101S11; Kailh_socket_MX
TP1, TP2: DNP; TestPoint_Loop_D1.80mm_Drill1.0mm_Beaded
U0, U5, U7, U8, U21: USBLC6-2SC6; SOT-23-6
U1: ATmega32U4-MU; QFN-44-1EP_7x7mm_P0.5mm_EP5.2x5.2mm
U2: USB7216C; QFN-100-1EP_12x12mm_P0.4mm_EP8x8mm
U3, U6, U15: CBTL02043ABQ,115; QFN-20-1EP_2.5x4.5mm_P0.5mm_EP1x3mm
U4, U17: AP3441LSHE-7B; W-DFN2020-8_Type_C
U9, U10, U20, U22, U23: AP22811AW5-7; SOT-23-5
U11: PTN5110DHQ; QFN-16-1EP_2.6x2.6mm_P0.4mm_EP1.1x1mm
U12, U13: PTN5110THQ; QFN-16-1EP_2.6x2.6mm_P0.4mm_EP1.1x1mm
U14, U19: SN74LVC1G08DCKR; SOT-353_SC-70-5
U16: AP22811AW5-7‎; SOT-23-5
U18: LP5907MFX-3.3; SOT-23-5
X1: ECS-3225MV-250-BN-TR; Oscillator_SMD_SeikoEpson_SG8002CE-4Pin_3.2x2.5mm
Y0: ECS-160-18-23G-JGN-TR; Crystal_SMD_0603-2Pin_6.0x3.5mm

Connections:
+1V1: C8.1, C17.1, C18.1, C19.1, C20.1, C21.1, C22.1, C23.1, C24.1, C34.1, C50.1, C68.1, L1.2, R14.1, U2.9, U2.18, U2.25, U2.31, U2.38, U2.55, U2.78, U2.85, U2.93
+3V3: C0.2, C1.1, C2.1, C3.1, C33.1, C36.1, C37.1, C38.1, C39.1, C40.1, C41.1, C42.1, C43.1, C55.1, C56.1, C57.1, C58.1, C63.1, J1.2, R5.1, R6.1, R7.1, R9.1, R10.1, R23.1, R31.1, R32.1, U1.6, U1.14, U1.24, U1.34, U1.44, U2.26, U2.43, U2.53, U2.62, U2.67, U2.79, U2.81, U2.82, U2.88, U2.99, U3.1, U3.6, U3.10, U6.1, U6.6, U6.10, U11.3, U11.11, U12.3, U12.11, U13.3, U13.11, U15.1, U15.6, U15.10, U18.5, X1.1, X1.4
+3V6: C35.1, C49.1, C59.1, C60.1, C61.1, C62.1, C64.1, C65.1, C66.1, C67.1, C69.1, L2.2, LA0.2, LA1.2, LA2.2, LA3.2, LA4.2, LA5.2, LB0.2, LB1.2, LB2.2, LB3.2, LB4.2, LB5.2, LC0.2, LC1.2, LC2.2, LC3.2, LC4.2, LC5.2, LD0.2, LD1.2, LD2.2, LD3.2, LD4.2, LD5.2, LE0.2, LE1.2, LE2.2, LE3.2, LE4.2, LE5.2, LF0.2, LF1.2, LF2.2, LF3.2, LF4.2, LG0.2, LG1.2, LG2.2, LG3.2, LG4.2, LG5.2, LH0.2, LH1.2, LH2.2, LH3.2, LH4.2, LH5.2, LI0.2, LI1.2, LI2.2, LI3.2, LI4.2, LI5.2, LJ0.2, LJ1.2, LJ2.2, LJ3.2, LJ4.2, LJ5.2, LK0.2, LK1.2, LK2.2, LK3.2, LK4.2, LK5.2, LL0.2, LL1.2, LL2.2, LL3.2, LL4.2, LL5.2, LM0.2, LM1.2, LM2.2, LM3.2, LM4.2, LM5.2, LN0.2, LN1.2, LN2.2, LO0.2, LO1.2, LO2.2, LO3.2, R25.1, U18.1, U18.3
/AVR_SCL: R9.2, TP1.1, U1.18, U2.75, U11.8, U12.8, U13.8
/AVR_SDA: R10.2, TP2.1, U1.19, U2.76, U11.7, U12.7, U13.7
/USB/AL_D+: U2.28, U8.1
/USB/AL_D-: U2.27, U8.3
/USB/AL_ESD_D+: J3.3, U8.6
/USB/AL_ESD_D-: J3.2, U8.4
/USB/AL_RX+: D6.2, D6.9, J3.6, U2.32
/USB/AL_RX-: D6.1, D6.10, J3.5, U2.33
/USB/AL_TX+: C54.1, D6.5, D6.6, U2.29
/USB/AL_TX-: C53.1, D6.4, D6.7, U2.30
/USB/AL_VBUS: C45.1, J3.1, U8.5, U10.1
/USB/AR_D+: U2.15, U5.1
/USB/AR_D-: U2.14, U5.3
/USB/AR_ESD_D+: J2.3, U5.6
/USB/AR_ESD_D-: J2.2, U5.4
/USB/AR_RX+: D2.2, D2.9, J2.6, U2.19
/USB/AR_RX-: D2.1, D2.10, J2.5, U2.20
/USB/AR_TX+: C52.1, D2.5, D2.6, U2.16
/USB/AR_TX-: C51.1, D2.4, D2.7, U2.17
/USB/AR_VBUS: C44.1, J2.1, U5.5, U23.1
/USB/AVR_USB_D+: R2.2, U2.42
/USB/AVR_USB_D-: R3.1, U2.41
/USB/AVR_VBUS: C4.1, R24.2, U1.7, U22.1
/USB/CL_BYP: C27.2, U13.4, U19.5
/USB/CL_CC1: J5.A5, U13.13
/USB/CL_CC2: J5.B5, U13.14
/USB/CL_D0+: J5.A6, J5.B6, U21.1
/USB/CL_D0-: J5.A7, J5.B7, U21.3
/USB/CL_D+: U2.34, U21.6
/USB/CL_D-: U2.35, U21.4
/USB/CL_EN: U19.4, U20.4
/USB/CL_RX1+: D7.2, D7.9, J5.B11, U15.14
/USB/CL_RX1-: D7.1, D7.10, J5.B10, U15.15
/USB/CL_RX2+: D8.5, D8.6, J5.A11, U15.19
/USB/CL_RX2-: D8.4, D8.7, J5.A10, U15.18
/USB/CL_RX+: U2.39, U15.4
/USB/CL_RX-: U2.40, U15.3
/USB/CL_SEL: U2.51, U15.9
/USB/CL_SRC: R16.1, U13.16, U19.1
/USB/CL_TX1+: C30.1, D7.5, D7.6, U15.12
/USB/CL_TX1-: C28.1, D7.4, D7.7, U15.13
/USB/CL_TX1D+: C30.2, J5.A2
/USB/CL_TX1D-: C28.2, J5.A3
/USB/CL_TX2+: C31.1, D8.1, D8.10, U15.16
/USB/CL_TX2-: C29.1, D8.2, D8.9, U15.17
/USB/CL_TX2D+: C31.2, J5.B3
/USB/CL_TX2D-: C29.2, J5.B2
/USB/CL_TX+: U2.36, U15.8
/USB/CL_TX-: U2.37, U15.7
/USB/CL_VBUS: C47.1, J5.A4, J5.A9, J5.B4, J5.B9, U13.15, U20.1, U21.5
/USB/CR_BYP: C26.2, U12.4, U14.5
/USB/CR_CC1: J4.A5, U12.13
/USB/CR_CC2: J4.B5, U12.14
/USB/CR_D0+: J4.A6, J4.B6, U7.1
/USB/CR_D0-: J4.A7, J4.B7, U7.3
/USB/CR_D+: U2.5, U7.6
/USB/CR_D-: U2.6, U7.4
/USB/CR_EN: U9.4, U14.4
/USB/CR_RX1+: D4.1, D4.10, J4.A11, U6.19
/USB/CR_RX1-: D4.2, D4.9, J4.A10, U6.18
/USB/CR_RX2+: D5.5, D5.6, J4.B10, U6.15
/USB/CR_RX2-: D5.4, D5.7, J4.B11, U6.14
/USB/CR_RX+: U2.11, U6.3
/USB/CR_RX-: U2.10, U6.4
/USB/CR_SEL: U2.73, U6.9
/USB/CR_SRC: R17.1, U12.16, U14.1
/USB/CR_TX1+: C13.1, D4.4, D4.7, U6.17
/USB/CR_TX1-: C15.1, D4.5, D4.6, U6.16
/USB/CR_TX1D+: C15.2, J4.B3
/USB/CR_TX1D-: C13.2, J4.B2
/USB/CR_TX2+: C14.1, D5.2, D5.9, U6.13
/USB/CR_TX2-: C16.1, D5.1, D5.10, U6.12
/USB/CR_TX2D+: C16.2, J4.A2
/USB/CR_TX2D-: C14.2, J4.A3
/USB/CR_TX+: U2.8, U6.7
/USB/CR_TX-: U2.7, U6.8
/USB/CR_VBUS: C46.1, J4.A4, J4.A9, J4.B4, J4.B9, U7.5, U9.1, U12.15
/USB/CS1: R11.1, U2.21
/USB/CS2: R12.1, U2.22
/USB/CS3: R13.1, U2.23
/USB/DP1_CC1: R33.1, U2.12
/USB/DP1_CC2: R34.1, U2.13
/USB/HUB_SCL: R31.2, U2.61
/USB/HUB_SDA: R32.2, U2.3
/USB/PRT_CTL1: U2.60, U9.3, U14.2
/USB/PRT_CTL2: U2.59, U23.3, U23.4
/USB/PRT_CTL3: U2.58, U10.3, U10.4
/USB/PRT_CTL4: U2.57, U19.2, U20.3
/USB/PRT_CTL6: U2.77, U22.3, U22.4
/USB/RBIAS: R1.1, U2.100
/USB/SPI_CLK: R29.1, U2.68
/USB/SPI_D0: R19.1, U2.70
/USB/SPI_D1: R30.1, U2.71
/USB/SPI_~CE: R20.1, U2.69
/USB/TEST1: R5.2, U2.63
/USB/TEST2: R6.2, U2.64
/USB/TEST3: R7.2, U2.65
/USB/UP_ADDR: R8.1, U11.5
/USB/UP_BYP: C25.2, R8.2, U11.4
/USB/UP_CC1: J0.A5, U11.13
/USB/UP_CC2: J0.B5, U11.14
/USB/UP_D0+: J0.A6, J0.B6, U0.1
/USB/UP_D0-: J0.A7, J0.B7, U0.3
/USB/UP_D1+: U0.6, U2.89
/USB/UP_D1-: U0.4, U2.90
/USB/UP_RX1+: D3.2, D3.9, J0.B11, U3.14
/USB/UP_RX1-: D3.1, D3.10, J0.B10, U3.15
/USB/UP_RX2+: D1.5, D1.6, J0.A11, U3.19
/USB/UP_RX2-: D1.4, D1.7, J0.A10, U3.18
/USB/UP_SEL: U2.74, U3.9
/USB/UP_TX1+: C12.1, D3.4, D3.7, U3.13
/USB/UP_TX1-: C11.1, D3.5, D3.6, U3.12
/USB/UP_TX1D+: C12.2, J0.A3
/USB/UP_TX1D-: C11.2, J0.A2
/USB/UP_TX2+: C9.1, D1.2, D1.9, U3.17
/USB/UP_TX2-: C10.1, D1.1, D1.10, U3.16
/USB/UP_TX2D+: C9.2, J0.B2
/USB/UP_TX2D-: C10.2, J0.B3
/USB/USB_UP_RX+: U2.94, U3.4
/USB/USB_UP_RX-: U2.95, U3.3
/USB/USB_UP_TX+: U2.91, U3.8
/USB/USB_UP_TX-: U2.92, U3.7
/USB/VBUS_DET: R21.2, R22.1, U2.2
/USB/VBUS_MON: R18.2, R28.1, U2.80
/USB/XTALI: U2.98, X1.3
/USB/~RESET: C7.1, R23.2, U2.1, U4.2, U17.2
/power/FB1V1: C68.2, R14.2, R15.1, U17.1
/power/FB3V6: C69.2, R25.2, R26.1, U4.1
/power/SW1V1: L1.1, U17.6
/power/SW3V6: L2.1, U4.6
COLA: SWA0.1, SWA1.1, SWA2.1, SWA3.1, SWA4.1, SWA5.1, U1.27
COLB: SWB0.1, SWB1.1, SWB2.1, SWB3.1, SWB4.1, SWB5.1, U1.32
COLC: SWC0.1, SWC1.1, SWC2.1, SWC3.1, SWC4.1, SWC5.1, U1.31
COLD: SWD0.1, SWD1.1, SWD2.1, SWD3.1, SWD4.1, SWD5.1, U1.30
COLE: SWE0.1, SWE1.1, SWE2.1, SWE3.1, SWE4.1, SWE5.1, U1.29
COLF: SWF0.1, SWF1.1, SWF2.1, SWF3.1, SWF4.1, SWF5.1, U1.28
COLG: SWG0.1, SWG1.1, SWG2.1, SWG3.1, SWG4.1, SWG5.1, U1.26
COLH: SWH0.1, SWH1.1, SWH2.1, SWH3.1, SWH4.1, SWH5.1, U1.25
COLI: SWI0.1, SWI1.1, SWI2.1, SWI3.1, SWI4.1, SWI5.1, U1.1
COLJ: SWJ0.1, SWJ1.1, SWJ2.1, SWJ3.1, SWJ4.1, SWJ5.1, U1.22
COLK: SWK0.1, SWK1.1, SWK2.1, SWK3.1, SWK4.1, SWK5.1, U1.21
COLL: SWL0.1, SWL1.1, SWL2.1, SWL3.1, SWL4.1, SWL5.1, U1.20
COLM: SWM0.1, SWM1.1, SWM2.1, SWM3.1, SWM4.1, SWM5.1, U1.12
COLN: SWN0.1, SWN1.1, SWN2.1, SWN3.1, SWN4.1, SWN5.1, U1.8
GND: C0.1, C1.2, C2.2, C3.2, C4.2, C5.2, C6.2, C7.2, C8.2, C17.2, C18.2, C19.2, C20.2, C21.2, C22.2, C23.2, C24.2, C25.1, C26.1, C27.1, C32.2, C33.2, C34.2, C35.2, C36.2, C37.2, C38.2, C39.2, C40.2, C41.2, C42.2, C43.2, C44.2, C45.2, C46.2, C47.2, C48.2, C49.2, C50.2, C55.2, C56.2, C57.2, C58.2, C59.2, C60.2, C61.2, C62.2, C63.2, C64.2, C65.2, C66.2, C67.2, D1.3, D1.8, D2.3, D2.8, D3.3, D3.8, D4.3, D4.8, D5.3, D5.8, D6.3, D6.8, D7.3, D7.8, D8.3, D8.8, H1.1, H2.1, H3.1, H4.1, H5.1, H6.1, H7.1, H8.1, H9.1, J0.A1, J0.A12, J0.B1, J0.B12, J0.S1, J1.6, J2.4, J2.7, J2.10, J3.4, J3.7, J3.10, J4.A1, J4.A12, J4.B1, J4.B12, J4.S1, J5.A1, J5.A12, J5.B1, J5.B12, J5.S1, LA0.4, LA1.4, LA2.4, LA3.4, LA4.4, LA5.4, LB0.4, LB1.4, LB2.4, LB3.4, LB4.4, LB5.4, LC0.4, LC1.4, LC2.4, LC3.4, LC4.4, LC5.4, LD0.4, LD1.4, LD2.4, LD3.4, LD4.4, LD5.4, LE0.4, LE1.4, LE2.4, LE3.4, LE4.4, LE5.4, LF0.4, LF1.4, LF2.4, LF3.4, LF4.4, LG0.4, LG1.4, LG2.4, LG3.4, LG4.4, LG5.4, LH0.4, LH1.4, LH2.4, LH3.4, LH4.4, LH5.4, LI0.4, LI1.4, LI2.4, LI3.4, LI4.4, LI5.4, LJ0.4, LJ1.4, LJ2.4, LJ3.4, LJ4.4, LJ5.4, LK0.4, LK1.4, LK2.4, LK3.4, LK4.4, LK5.4, LL0.4, LL1.4, LL2.4, LL3.4, LL4.4, LL5.4, LM0.4, LM1.4, LM2.4, LM3.4, LM4.4, LM5.4, LN0.4, LN1.4, LN2.4, LO0.4, LO1.4, LO2.4, LO3.4, R1.2, R4.2, R11.2, R12.2, R13.2, R15.2, R16.2, R17.2, R19.2, R20.2, R22.2, R26.2, R28.2, R29.2, R30.2, R33.2, R34.2, U0.2, U1.5, U1.15, U1.23, U1.35, U1.43, U1.45, U2.24, U2.101, U3.2, U3.5, U3.11, U3.20, U3.21, U4.4, U4.8, U4.9, U5.2, U6.2, U6.5, U6.11, U6.20, U6.21, U7.2, U8.2, U9.2, U10.2, U11.17, U12.5, U12.17, U13.17, U14.3, U15.2, U15.5, U15.11, U15.20, U15.21, U16.2, U17.4, U17.8, U17.9, U18.2, U19.3, U20.2, U21.2, U22.2, U23.2, X1.2
LED: R4.1, R27.2, U1.33
MISO: J1.1, U1.11
MOSI: J1.4, U1.10
unnamed: C5.1, U1.17, Y0.2
unnamed: C6.1, U1.16, Y0.1
unnamed: C51.2, J2.8
unnamed: C52.2, J2.9
unnamed: C53.2, J3.8
unnamed: C54.2, J3.9
unnamed: D9.1, SWA0.2
unnamed: D9.2, SWB0.2
unnamed: D10.1, SWA1.2
unnamed: D10.2, SWB1.2
unnamed: D11.1, SWA2.2
unnamed: D11.2, SWB2.2
unnamed: D12.1, SWA3.2
unnamed: D12.2, SWB3.2
unnamed: D13.1, SWA4.2
unnamed: D13.2, SWB4.2
unnamed: D14.1, SWA5.2
unnamed: D14.2, SWB5.2
unnamed: D15.1, SWM0.2
unnamed: D15.2, SWN0.2
unnamed: D16.1, SWN1.2
unnamed: D16.2, SWM1.2
unnamed: D17.1, SWN2.2
unnamed: D17.2, SWM2.2
unnamed: D18.1, SWM3.2
unnamed: D18.2, SWN3.2
unnamed: D19.1, SWM4.2
unnamed: D19.2, SWN4.2
unnamed: D20.1, SWM5.2
unnamed: D20.2, SWN5.2
unnamed: D21.1, SWK0.2
unnamed: D21.2, SWL0.2
unnamed: D22.1, SWL1.2
unnamed: D22.2, SWK1.2
unnamed: D23.1, SWK2.2
unnamed: D23.2, SWL2.2
unnamed: D24.1, SWK3.2
unnamed: D24.2, SWL3.2
unnamed: D25.1, SWK4.2
unnamed: D25.2, SWL4.2
unnamed: D26.1, SWK5.2
unnamed: D26.2, SWL5.2
unnamed: D27.1, SWI0.2
unnamed: D27.2, SWJ0.2
unnamed: D28.1, SWJ1.2
unnamed: D28.2, SWI1.2
unnamed: D29.1, SWI2.2
unnamed: D29.2, SWJ2.2
unnamed: D30.1, SWI3.2
unnamed: D30.2, SWJ3.2
unnamed: D31.1, SWI4.2
unnamed: D31.2, SWJ4.2
unnamed: D32.1, SWI5.2
unnamed: D32.2, SWJ5.2
unnamed: D33.1, SWG0.2
unnamed: D33.2, SWH0.2
unnamed: D34.1, SWG1.2
unnamed: D34.2, SWH1.2
unnamed: D35.1, SWG2.2
unnamed: D35.2, SWH2.2
unnamed: D36.1, SWG3.2
unnamed: D36.2, SWH3.2
unnamed: D37.1, SWG4.2
unnamed: D37.2, SWH4.2
unnamed: D38.1, SWG5.2
unnamed: D38.2, SWH5.2
unnamed: D39.1, SWE0.2
unnamed: D39.2, SWF0.2
unnamed: D40.1, SWF1.2
unnamed: D40.2, SWE1.2
unnamed: D41.1, SWF2.2
unnamed: D41.2, SWE2.2
unnamed: D42.1, SWE3.2
unnamed: D42.2, SWF3.2
unnamed: D43.1, SWE4.2
unnamed: D43.2, SWF4.2
unnamed: D44.1, SWF5.2
unnamed: D44.2, SWE5.2
unnamed: D45.1, SWC0.2
unnamed: D45.2, SWD0.2
unnamed: D46.1, SWC1.2
unnamed: D46.2, SWD1.2
unnamed: D47.1, SWD2.2
unnamed: D47.2, SWC2.2
unnamed: D48.1, SWC3.2
unnamed: D48.2, SWD3.2
unnamed: D49.1, SWD4.2
unnamed: D49.2, SWC4.2
unnamed: D50.1, SWC5.2
unnamed: D50.2, SWD5.2
unnamed: LA0.1, LA1.3
unnamed: LA0.3, LB0.1
unnamed: LA1.1, LB1.3
unnamed: LA2.1, LA3.3
unnamed: LA2.3, LB2.1
unnamed: LA3.1, LB3.3
unnamed: LA4.1, LB4.3
unnamed: LA4.3, LA5.1
unnamed: LA5.3, LB5.1
unnamed: LB0.3, LC0.1
unnamed: LB1.1, LC1.3
unnamed: LB2.3, LC2.1
unnamed: LB3.1, LC3.3
unnamed: LB4.1, LC4.3
unnamed: LB5.3, LC5.1
unnamed: LC0.3, LD0.1
unnamed: LC1.1, LD1.3
unnamed: LC2.3, LD2.1
unnamed: LC3.1, LD3.3
unnamed: LC4.1, LD4.3
unnamed: LC5.3, LD5.1
unnamed: LD0.3, LE0.1
unnamed: LD1.1, LE1.3
unnamed: LD2.3, LE2.1
unnamed: LD3.1, LE3.3
unnamed: LD4.1, LE4.3
unnamed: LD5.3, LE5.1
unnamed: LE0.3, LF0.1
unnamed: LE1.1, LF1.3
unnamed: LE2.3, LF2.1
unnamed: LE3.1, LF3.3
unnamed: LE4.1, LF4.3
unnamed: LE5.3, LG5.1
unnamed: LF0.3, LG0.1
unnamed: LF1.1, LG1.3
unnamed: LF2.3, LG2.1
unnamed: LF3.1, LG3.3
unnamed: LF4.1, LG4.3
unnamed: LG0.3, LH0.1
unnamed: LG1.1, LH1.3
unnamed: LG2.3, LH2.1
unnamed: LG3.1, LH3.3
unnamed: LG4.1, LH4.3
unnamed: LG5.3, LH5.1
unnamed: LH0.3, LI0.1
unnamed: LH1.1, LI1.3
unnamed: LH2.3, LI2.1
unnamed: LH3.1, LI3.3
unnamed: LH4.1, LI4.3
unnamed: LH5.3, LI5.1
unnamed: LI0.3, LJ0.1
unnamed: LI1.1, LJ1.3
unnamed: LI2.3, LJ2.1
unnamed: LI3.1, LJ3.3
unnamed: LI4.1, LJ4.3
unnamed: LI5.3, LJ5.1
unnamed: LJ0.3, LK0.1
unnamed: LJ1.1, LK1.3
unnamed: LJ2.3, LK2.1
unnamed: LJ3.1, LK3.3
unnamed: LJ4.1, LK4.3
unnamed: LJ5.3, LK5.1
unnamed: LK0.3, LL0.1
unnamed: LK1.1, LL1.3
unnamed: LK2.3, LL2.1
unnamed: LK3.1, LL3.3
unnamed: LK4.1, LL4.3
unnamed: LK5.3, LL5.1
unnamed: LL0.3, LM0.1
unnamed: LL1.1, LM1.3
unnamed: LL2.3, LM2.1
unnamed: LL3.1, LM3.3
unnamed: LL4.1, LM4.3
unnamed: LL5.3, LM5.1
unnamed: LM0.3, LN0.1
unnamed: LM1.1, LN1.3
unnamed: LM2.3, LN2.1
unnamed: LM3.1, LO3.3
unnamed: LM4.1, R27.1
unnamed: LM5.3, LO3.1
unnamed: LN0.3, LO0.1
unnamed: LN1.1, LO1.3
unnamed: LN2.3, LO2.1
unnamed: LO1.1, LO2.3
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

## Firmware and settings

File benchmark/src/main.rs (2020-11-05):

use chrono::Local;
use futures::stream::StreamExt;
use memmap::MmapMut;
use std::{
    fs::{self, OpenOptions},
    io::{Read, Seek, SeekFrom},
    os::unix::fs::OpenOptionsExt,
    time::Instant,
};
use usb_disk_probe::stream::UsbDiskProbe;

fn format_speed(speed: u128) -> String {
    if speed > 4 * 1024 * 1024 * 1024 {
        format!("{} GiB/s", speed / 1024 / 1024 / 1024)
    } else if speed > 4 * 1024 * 1024 {
        format!("{} MiB/s", speed / 1024 / 1024)
    } else if speed > 4 * 1024 {
        format!("{} KiB/s", speed / 1024)
    } else {
        format!("{} B/s", speed)
    }
}

fn main() {
    let mut paths: Vec<std::path::PathBuf> = Vec::new();
    futures::executor::block_on(async {
        let mut stream = UsbDiskProbe::new().await.expect("failed to find USB disks");
        while let Some(path_res) = stream.next().await {
            let path = path_res.expect("failed to read USB disk path");
            paths.push(path.to_path_buf().into());
        }
    });
    for path in paths.iter_mut() {
        let canonical = fs::canonicalize(&path).expect(&format!(
            "failed to get canonical path for USB disk: {}",
            path.display()
        ));
        eprintln!("{}: {}", path.display(), canonical.display());
        *path = canonical;
    }
    paths.sort();

    let mut disks = Vec::new();
    for path in paths {
        let file = OpenOptions::new()
            .read(true)
            .custom_flags(libc::O_DIRECT)
            .open(&path)
            .expect(&format!(
                "failed to open USB disk: {}",
                path.display()
            ));

        let buf = MmapMut::map_anon(4096 * 4096)
            .expect("failed to map read buffer");

        disks.push((
            path,
            file,
            buf,
            0u128,
        ));
    }

    loop {
        let date = Local::now();
        for (path, file, buf, speed) in disks.iter_mut() {
            file.seek(SeekFrom::Start(0)).expect(&format!(
                "failed to seek USB disk: {}",
                path.display()
            ));

            let elapsed = {
                let instant = Instant::now();
                file.read(buf).expect(&format!(
                    "failed to read USB disk: {}",
                    path.display()
                ));
                instant.elapsed()
            };

            let nanos = elapsed.as_nanos();
            *speed = (buf.len() as u128 * 1_000_000_000u128) / nanos;
        }

        eprintln!();
        eprintln!("\x1B[1m{}\x1B[0m", date.format("%Y-%m-%d %H:%M:%S"));
        for (path, _file, _buf, speed) in disks.iter() {
            eprintln!("{}: {}", path.display(), format_speed(*speed));
        }
    }
}

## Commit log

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2020-03-05 Rename to launch, add matrix and EC support structure
    [launch.kicad_pcb, launch.sch, virgo-keyboard.kicad_pcb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]
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2020-03-06 Fix references to switches and diodes
    [launch.sch]
2020-03-06 Position switches in PCB
    [launch.kicad_pcb]
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2020-03-07 Finish routing of matrix
    [launch.kicad_pcb]
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2020-03-07 Add RBG LED matrix
    [launch.kicad_pcb, launch.sch]
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2020-03-07 Route rows to EC
    [launch.kicad_pcb]
2020-03-08 Connect everything in schematic
    [launch.kicad_pcb, launch.sch]
2020-03-09 Route LED data in to EC
    [launch.kicad_pcb, launch.sch]
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2020-03-09 Reroute to remove space at top of board
    [launch.kicad_pcb, launch.sch]
2020-03-10 Add ICSP header and add socket model
    [CPG151101S11.stp, launch.kicad_pcb, launch.sch]
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2020-03-10 Add ISP header to BOM
    [launch-bom.csv]
2020-05-08 Add Kailh switch model to socket footprint
    [CPG1511F01S11.stp, launch.kicad_pcb]
2020-07-23 work in progress on USB hub addition Incomplete: USB Vbus caps on all 4 downstream ports reset to hub review checklist and eval board design C left ESD, etc key matrix ESD 1.1 V may need to be 1.15 V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
    [M-12401610E42A-REVT2.stp, USB.sch, launch.kicad_pcb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]
2020-07-29 USB hub schematic Review USB7206 checklist, implement changes added pull down resistors to source enable on TCPCs added note on 1.1 V to consider increasing to 1.15 V added 150 uF caps on Vbus added 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
    [USB.sch, launch.sch, power.sch]
2020-07-29 directly ground USB A connectors
    [USB.sch]
2020-07-29 use dual diodes in keyboard matrix
    [launch.sch]
2020-07-31 change to USB mid mount, misc add AC coupling caps to A connectors change programming header to tag connect
    [1003-002-01100.stp, USB.sch, launch.sch]
2020-08-04 100% routed needs: review intra pair delay matching ground cutouts fab notes
    [USB.sch, launch.kicad_pcb, launch.sch]
2020-08-10 PCB diff pair skew, cutouts, etc arrange silkscreen ground plane cutouts under large high speed pads intra pair skew matching general cleanup
    [launch.kicad_pcb, launch.sch]
2020-08-11 correct USB A part number, add inductor part number
    [USB.sch, launch.kicad_pcb, power.sch]
2020-08-11 fix min solder mask width this was causing no mask to be present between a few QFN ground pads and leads
    [launch.kicad_pcb]
2020-09-02 remove key matrix ESD note issue #6
    [launch.sch]
2020-09-02 correct 1.1 V supply set point resistors closes #2
    [power.sch]
2020-09-02 use PE2 for LED instead of key matrix closes #7 @jackpot51, note some column lines were swapped for layout purposes
    [launch.kicad_pcb, launch.sch]
2020-09-02 fix Kailh_socket footprint Put the SMD pads on the top layer so it appears in the correct pick and place file Flipped the entire footprint, then all instances of it on the PCB. closes #1
    [launch.kicad_pcb]
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2020-09-02 reduce paste mask opening size by 25 μm on USB7206 Issue #5
    [launch.kicad_pcb]
2020-09-02 flip 3D models in key footprint too Issue #1
2020-09-02 Use smaller LEDs for key clearance Issue #8 Increased 3.6 V supply to 3.74 V to support new LEDs LEDs moved to 5.05 mm above center peg of key
    [LED_1515.FCStd, LED_1515.step, USB.sch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]
2020-09-02 add LED decoupling Issue #8
    [launch.kicad_pcb, power.sch]
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2020-09-09 Change SS mux to CBTL02043 for larger easier to solder footprint control IO moved from the TCPCs to the USB hub closes #4
    [SOT764-1.step, USB.sch, launch.kicad_pcb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]
2020-09-09 adjust trace widths, stackup for as-built controlled impedance
    [launch.kicad_pcb]
2020-09-09 Add additional solder paste are to pin in paste pads to increase solder volume and/or allow for a solder preform to be placed
    [launch.kicad_pcb]
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2020-09-10 schematic cleanup no electrical changes fix overlapping text add notes add manufacturer part number for AVR crystal
    [USB.sch, launch.kicad_pcb, launch.sch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]
2020-09-17 ground cutouts, ground plane continuity Add ground plane cutouts on D1 Add small ground plane cutouts on USB7206 move 2 vias near U15 slightly to improve ground plane continuity
    [launch.kicad_pcb]
2020-09-18 BOM update Add manufacturer info Add key socket PN Correct USB-A to surface mount (was through hole)
    [USB.sch, launch.kicad_pcb, launch.sch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]
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2020-09-18 plated mounting holes adjust position of one mounting hole slightly add hole near middle.
    [launch.kicad_pcb, launch.sch]
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2020-09-27 Adjustments for production Change laminate from ITEQ IT180A to Shengyi S1000-2 - Associated controlled impedance changes Remove circles on Cmts.User in mounting holes that were confusing manufacturer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
    [launch.kicad_pcb]
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2020-10-28 change VBUS caps to as-built part is taller
    [USB.sch, launch-bom.csv, launch.kicad_pcb]
2020-11-11 increase size of USB C pads for hand soldering only pads on opposite side of connector
    [launch.kicad_pcb]
2020-11-11 fix DRC error
    [launch.kicad_pcb]
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2021-05-20 add copper areas to switch pads this should help prevent them from tearing off if a key is misaligned or has bent pins when inserted
    [launch.kicad_pcb]
2021-05-20 add components to support USB7216 The USB7216 uses an alternate location, pin 80 for VBUS monitoring. This adds a voltage divider, R18 and R28 which should only be installed if a USB7216 is used. Pad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
    [USB.sch, launch.kicad_pcb]
2021-05-20 add minimum thickness for outer copper It's in IPC-A-600, but adding to be clear there is a minimum copper requirement
    [launch.kicad_pcb]
2021-05-20 revert accidental removal of System76 logo
    [launch.kicad_pcb]
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2021-05-21 Ensure correct VBUS capacitor part number
    [USB.sch, launch-bom.csv, launch.kicad_pcb]
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2021-05-21 Correct VBUS capacitors model
    [launch.kicad_pcb]
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2021-05-27 Use AP61302 for regulating 1V1 and 3V6 power planes
    [launch-bom.csv, launch.kicad_pcb, power.sch]
2021-05-27 minor layout adjustments, feedforward cap value Change feedforward cap to 330 pF so the transfer function of the feedback network will be similar to that of the datasheet example. Our feedback resist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
    Correct typo in notes on power schematic page.
    Change buck feedforward cap footprint from Kicad lib to launch lib for consistency.
    Arrange schematic components so "330 pF" does not overlap adjacent components.
    Move "U4" silkscreen to not overlap inductor pad.
    Add a 2nd via to each buck converter ground, move feedback components to allow.
    Reroute some signal traces to reduce number of vias, have more solid grou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
    [USB.sch, launch-bom.csv, launch.kicad_pcb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]
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2021-09-13 Fix library references for symbols renamed in upstream also remove cache from gitignore, include in repo in case user's libaries don't align.
    [USB.sch, launch.sch]
2021-11-15 use AP3441LSHE-7B DC-DC switching to available part from long lead time part adds 2 22 uF 0805 capacitors as well
    [USB.sch, launch-bom.csv, launch.kicad_pcb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]
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2022-03-09 add initial lite design based on standard launch uses AT90USB646 (more pins, availability no USB hub relaxes PCB requirements to 5/5 mil track, space, 0.5/0.25 mm vias
    [TYPE-C-31-M-12--3DModel-STEP-56544.STEP, launch-lite.kicad_sch, power.kicad_sch]
2022-03-09 launch lite finalization set version to 1.0 copper to NPTH clearance increased to 0.5 mm reroute a few traces move entire PCB by 50, 50 mm to get off of sheet frame
    [launch-lite.kicad_sch, power.kicad_sch]
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2022-04-04 Fix launch chassis broken image in README
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2022-06-21 move to Kicad 6, share libs with lite
    [USB.kicad_sch, USB.sch, launch.kicad_sch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]
2022-06-21 tenkey work in progress needs via stitching, decoupling, cleanup, etc
    [FH12-16S-0.5SH.step, launch-tenkey.kicad_pcb, launch-tenkey.kicad_sch]
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2022-06-21 version pins, finalize routing FFC connector changed to 20 pin USB hub reset pull down via stitching route remaining nets and cleanup
    [AFC07-S20FCC-00.FCStd, AFC07-S20FCC-00.step, FH12-16S-0.5SH.step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]
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2022-06-21 set version, change ISO to lower case in silkscreen
    [launch-lite-iso.kicad_sch, power.kicad_sch]
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2022-08-03 radius switch pads for more clearance
2022-08-03 launch heavy 1.1 move mounting holes to allow room for stabilizers no schematic changes round switch pads for improved clearance relocate D14 for mounting hole clearance
    [launch-heavy.kicad_pcb, launch-heavy.kicad_sch]
2022-08-13 launch-iso based on launch 2.0 remove unused mounting holes add diode footprint to local lib as the Kicad one changed
    [USB.kicad_sch, launch-iso.kicad_sch, power.kicad_sch]
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2023-08-25 RP2040, USB7216 Change USB hub part number to USB7216 Change microcontroller to RP2040 remove vbus switch for microcontroller as RP2040 does not require vbus sensing
    [USB.kicad_sch, launch.kicad_sch, power.kicad_sch]
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2023-08-25 fix swapped SDA, SCL at U1 fix parts overhanging schematic edge
    [USB.kicad_sch, launch.kicad_sch]
2023-08-25 resolve schematic ERC
    [launch.kicad_sch]
2023-08-25 change AVR to UC on some net names since we don't have an Atmel AVR controller now
    [USB.kicad_sch, launch.kicad_sch, power.kicad_sch]
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2023-08-25 launch 3.1 LED ESD mitigation - ground plane on top, move some traces to inner add cutouts to make removing from chassis easier AP22802 is no longer an allowed substitution
    [USB.kicad_sch, launch.kicad_sch, power.kicad_sch]
2023-08-25 hub reset handled by DC-DC power good switch to TLV62585P DC-DC for power good remove reset button - can just plug cable add buttons to ground SDA, SCL as hub bypass to allow programming
    [USB.kicad_sch, launch.kicad_sch, power.kicad_sch]
2023-08-25 single button for DFU boot also some ground stitching
    [USB.kicad_sch, launch.kicad_sch, power.kicad_sch]
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2023-08-30 VBUS protection circuitry add capacitors at every USB power switch add reverse protection schottky diode to clamp observed negative voltages seen on VBUS during plug and unplug add RC snubber to VBUS
    [SOD128.FCStd, SOD128.step, USB.kicad_sch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]
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
